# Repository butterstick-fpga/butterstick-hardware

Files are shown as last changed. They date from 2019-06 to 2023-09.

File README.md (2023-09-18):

# ButterStick

    A compact Lattice ECP5 based development board with breakouts for lots of high-speed I/O and serdes.

    With onboard DDR3, High Speed USB and Ethernet.

## Latest Revision: 
* __Latest Release:__ [ButterStick r1.0](hardware/ButterStick_r1.0/) 
  * Assembled PCBs available: [GroupGets](https://store.groupgets.com/products/butterstick-fpga-development-board)
  * Bare PCBs available: [Tindie](https://www.tindie.com/products/greeeg/butterstick-r10-bare-circuit-board)

Previous Revisions:
* [ButterStick r0.2](hardware/ButterStick_r0.2/)
* [ButterStick r0.1](hardware/ButterStick_r0.1/)

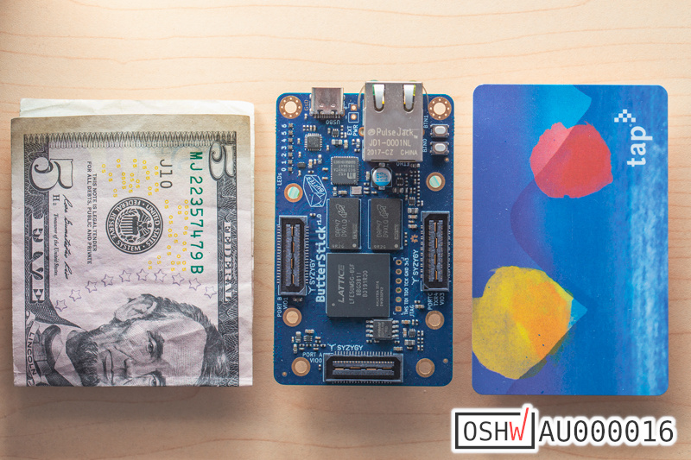
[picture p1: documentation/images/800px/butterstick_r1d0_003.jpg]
Populated ButterStick r1.0 board with Size Comparison


## Hardware (r1.0)

* ECP5 25F/45F/85F (BGA381 package)
* USB 2.0 High Speed (480 Mbit/s)
* Gigabit Ethernet
* upto 8Gbit DDR3L RAM (dual rank)
* 128Mbit QSPI FLASH Memory (Bitstream + User storage)
* MicroSD socket (4 bit SD interface)
* Onboard oscillators:
  * 30 MHz (ECP5's PLLs can create 60MHz,125MHz,etc.)
  * 25 MHz (RGMII PHY)
* 0.1" pitch JTAG connector
* 7x User RGB LEDs
* 2x User Buttons
* 2x Standard [SYZYGY compatible connectors](https://syzygyfpga.io/)
  * Adjustable VCCIO 1.2V-3.3V
  * Up to 32 single ended I/O
  * 10 differential pairs
  * Dedicated clock input pins
* 1x Transceiver [SYZYGY compatible connector](https://syzygyfpga.io/)
  * Adjustable VCCIO 1.2V-3.3V
  * Up to 14 single ended I/O
  * 2x/4x Lanes TX (5 Gbps SERDES)
  * 2x/4x Lanes RX (5 Gbps SERDES)
  * 1x Reference clock input

Board dimensions: 80mm x 49mm

### Variants

The ButterStick can be configured in different variants,
the part number defines which FPGA and DDR3 parts are installed.

`ButterStick-r1.0-[Memory gigabits]-[FPGA density]`

| | ButterStick-r1.0-2G-25F | ButterStick-r1.0-2G-85F | ButterStick-r1.0-8G-85F | 
|---|---|---|---|
| FPGA  | LFE5UM5G-25F-8BG381C | LFE5UM5G-85F-8BG381C | LFE5UM5G-85F-8BG381C | 
| DDR3  | 2x MT41K64M16TW-107 | 2x MT41K64M16TW-107 | 2x MT41K256M16TW-107 |

The 25F also has the following limitations on the ButterStick:
* 25F Only provides 2x SERDES lanes.
* 25F does not connect I/O pins S8/S9 on SYZYGY.C

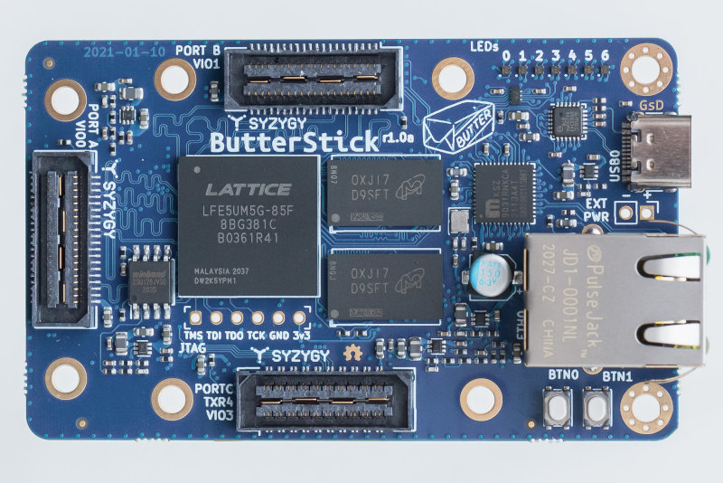
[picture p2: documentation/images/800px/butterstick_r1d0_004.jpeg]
Populated r1.0 board front

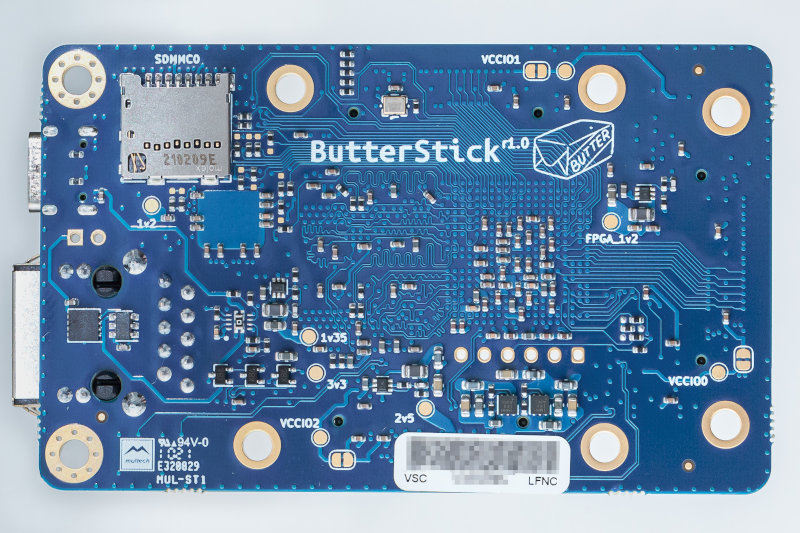
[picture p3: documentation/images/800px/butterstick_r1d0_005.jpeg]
Populated r1.0 board back


## Licence

 * Hardware in this repository is licensed under CERN OHL v1.2

 ## Open Source Hardware
This board is an OSHWA approved design: [AU000016](https://certification.oshwa.org/au000016.html)

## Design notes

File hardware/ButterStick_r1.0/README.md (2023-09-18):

# ButterStick r1.0
## ECP5 SYZYGY development board.
 
---

## What is it?
ECP5 based development board with on-board Gigabit Ethernet, High speed USB, and Lots of I/O broken out on SYZYGY connectors.

## Hardware Overview 
* Lattice ECP5-45F/85F FPGA in BGA381 package
* DDR3L Memory (dual rank)
* USB-C USB2.0 connection
    * High-speed (480Mbit) ULPI PHY
* Non-volatile Storage
    * 128Mbit QSPI FLASH Memory 
    * MicroSD socket
        * 4bit SD interface (CK, CMD, DAT0-3)
* Power supply
    * USB-C 5V input.
    * Aux 5V power input.
* onboard oscillator
    * 60Mhz
    * 25MHz (RGMII PHY)
* 0.1" JTAG connector
* User I/O
    * 2x Button 
    * 7x RGB LED
* Board dimensions
    * Dimensions: 80mm x 49mm (Golden Ratio!)

---

## Licence

 * Hardware in this repository is licensed under CERN OHL v1.2

## Open Source Hardware
This board is an OSHWA approved design: [AU000016](https://certification.oshwa.org/au000016.html)

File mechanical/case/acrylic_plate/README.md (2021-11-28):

# Acrylic Plate for Butterstick

This is a basic acrylic plate for butterstick described in openscad.  A dxf file is included for laser cutting.

It was cut in 3mm acrylic. The hardware is all M3, the bolts are 12mm long, the spacers are 5mm high.

Files are free to use in any form, no warranty is offered or implied.

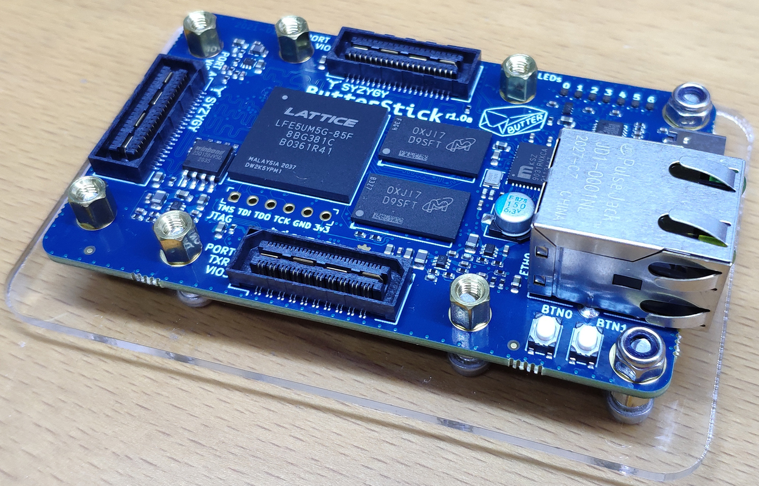
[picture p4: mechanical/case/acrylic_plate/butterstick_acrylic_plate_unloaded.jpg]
Loaded


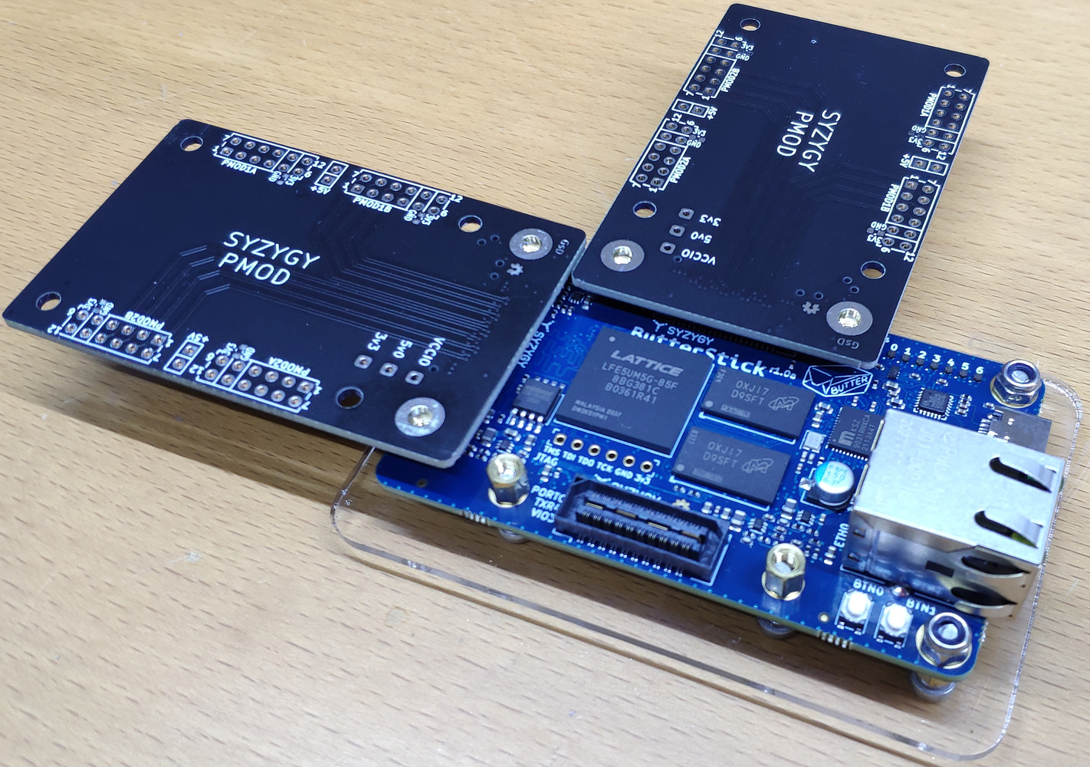
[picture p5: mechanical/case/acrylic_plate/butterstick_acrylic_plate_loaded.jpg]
Unloaded


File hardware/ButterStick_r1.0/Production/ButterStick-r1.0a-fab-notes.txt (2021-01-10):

Part number:        ButterStick-r1.0a

General fabrication notes

    * Boards panelised in 2x1 pattern using tab/route.
    * Board material is S1000-2
    
    * Blue solder mask on both sides of board.
    * High DPI White LPI legend on both sides of board.
    * Pad finish is ENIG.
    
    * All 0.2mm vias capped/filled/plated over (Via in Pad).

    * Finished board thickness is 1.6 mm.
    
    * Place UL mark/date code/manufacture logo on legend on backside of board.

Impedances

    Control to within 10%.
    Layer 1 microstrip (ref to layer 2)
        89 μm trace / 161 μm space = 100 ohm differential

    Layer 3 microstrip (ref to layer 2/4)
        89 μm trace / 161 μm space = 100 ohm differential
    
    Layer 6 microstrip (ref to layer 7/5)
        89 μm trace / 161 μm space = 100 ohm differential

    Layer 8 microstrip (ref to layer 7)
        89 μm trace / 161 μm space = 100 ohm differential

Suggested stackup
    1   35 μm (1 oz) copper         Signal
        0.075mm prepreg
    2   35 μm (1 oz) copper         Ground
        0.130mm core
    3   35 μm (1oz) copper          Signal
        prepreg as needed for 1.6mm finished PCB thickness
    4   35 μm (1 oz) copper         Power
        core as needed for 1.6mm finished PCB 
    5   35 μm (1oz) copper          Ground
        prepreg as needed for 1.6mm finished PCB thickness
    6   35 μm (1 oz) copper         Signal
        0.130mm core/prepreg
    7   35 μm (1 oz) copper         Ground
        0.075mm prepreg
    8   35 μm (1 oz) copper         Signal

File naming
    ButterStick.gko                  Board outline
    ButterStick-PTH.drl              Through-board plated holes
    ButterStick-NPTH.drl             Through-board unplated holes
    ButterStick.gto                  Front silkscreen
    ButterStick.gts                  Front solder mask
    ButterStick.gtl                  Layer 1 copper (Front)
    ButterStick.g2                   Layer 2 copper
    ButterStick.g3                   Layer 3 copper
    ButterStick.g4                   Layer 4 copper
    ButterStick.g5                   Layer 5 copper
    ButterStick.g6                   Layer 6 copper
    ButterStick.g7                   Layer 7 copper
    ButterStick.gbl                  Layer 8 copper (Back)
    ButterStick.gbs                  Back solder mask
    ButterStick.gbo                  Back silkscreen

    ButterStick.gtp                  Top Paste
    ButterStick.gbp                  Bottom Paste

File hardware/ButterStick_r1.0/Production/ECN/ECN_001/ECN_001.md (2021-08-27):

> Company: GsD / GroupGets  
> Project: ButterStick r1.0 

# Engineering Change Notice (ECN)

|||
|-|-|
**ECN Number** | 001  
**Origination Date** | Friday, 27th August, 2021
**Originator of Change** | Gregory Davill
**Project Name** | ButterStick r1.0
**Type of Action** | Part Substitution
**Reason for Change** | Remove difficult to source component from design

## Detailed description of changes

### Replace BOM item `U18`  
   ||Mfg|Part|
   |-|-|-|
   **Old** | Texas Instruments| TPS2121RUXR  
   **New** | YAGEO| RC0603JR-130RL  

### Populate new part on PCB
   Install `U18` such that it shorts pins 1,2 and 7,8 of `U18`  
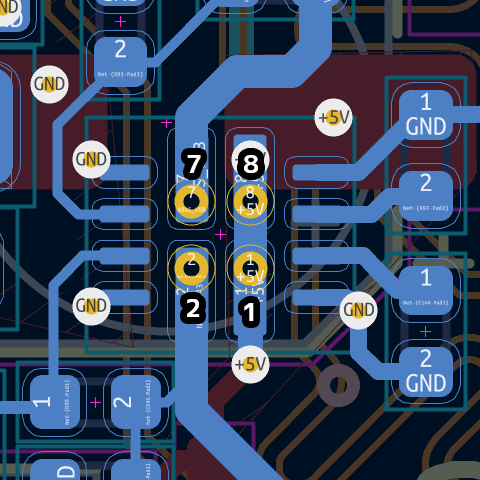
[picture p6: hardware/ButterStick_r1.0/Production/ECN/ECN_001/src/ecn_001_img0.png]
ecn_001_img0
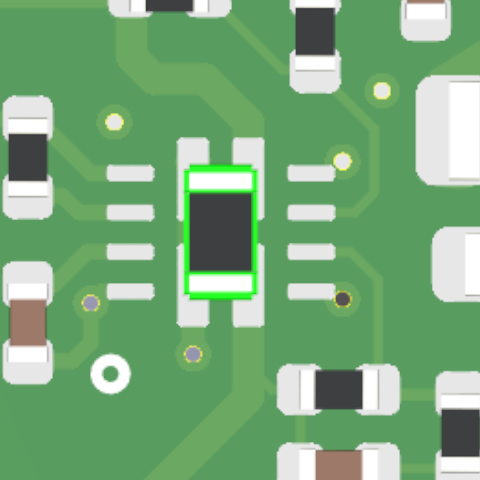
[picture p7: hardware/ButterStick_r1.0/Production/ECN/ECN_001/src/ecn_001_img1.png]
ecn_001_img1
      

> Note CAD view is Top view (Through the PCB). Whereas render view is Bottom View.

## QC checks

 Skew of `U18` is acceptable, and expected.  
 Acceptance criteria on soldering is that it's successfully soldered across pins 1,2 and 7,8 of `U18`

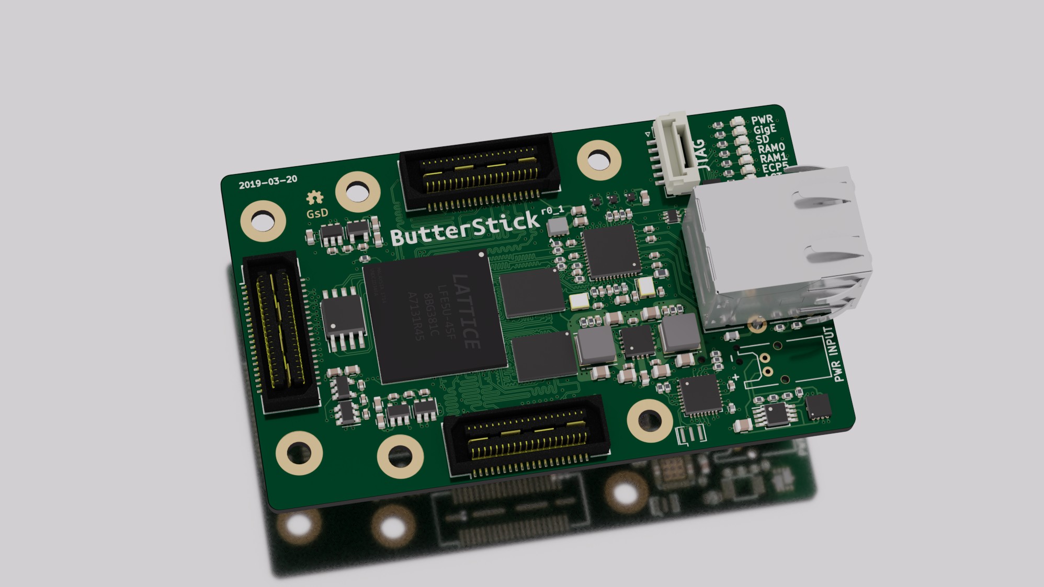
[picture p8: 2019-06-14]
hardware/ButterStick_r0.1/plot/render_001.jpg

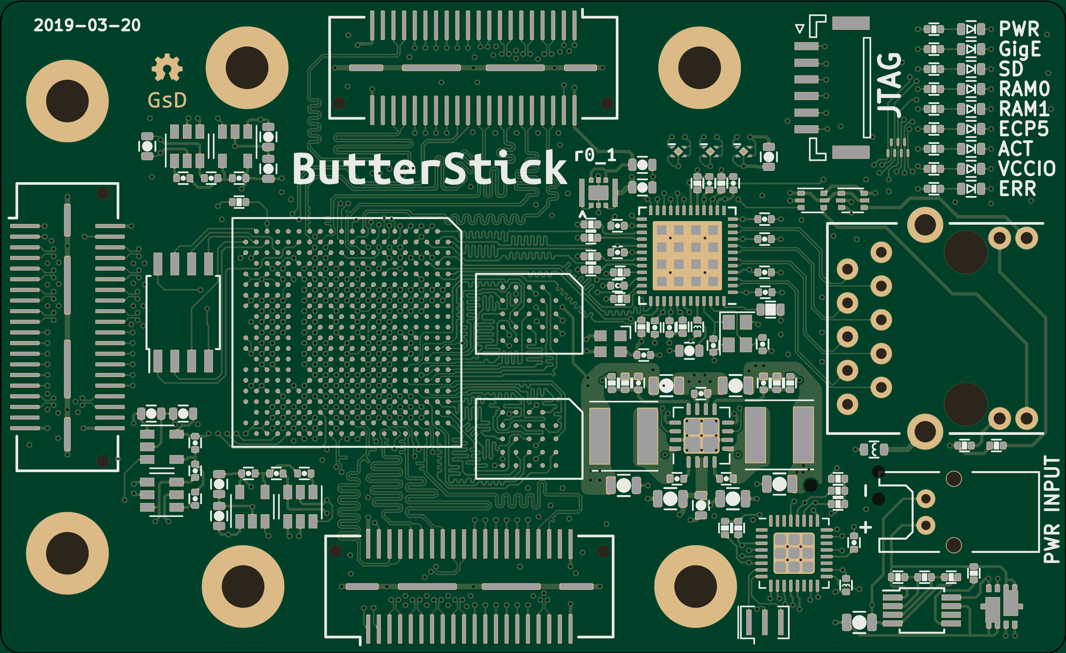
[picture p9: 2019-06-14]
hardware/ButterStick_r0.1/plot/ButterStick-Front.png

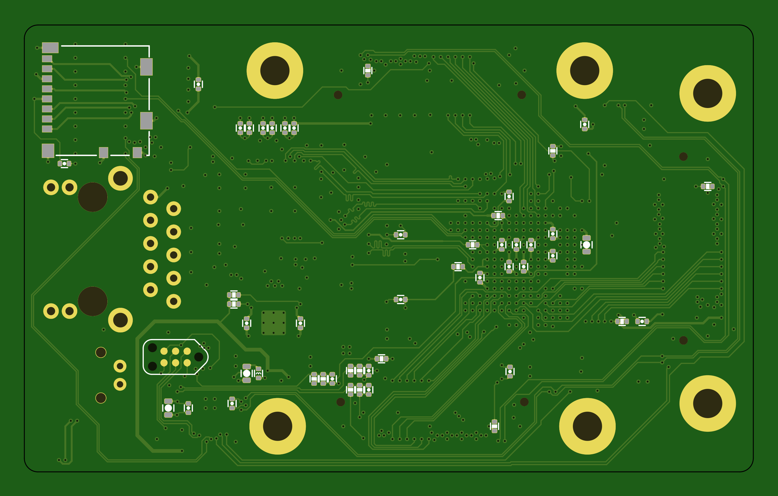
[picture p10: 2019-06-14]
hardware/ButterStick_r0.1/plot/ButterStick-Back.png

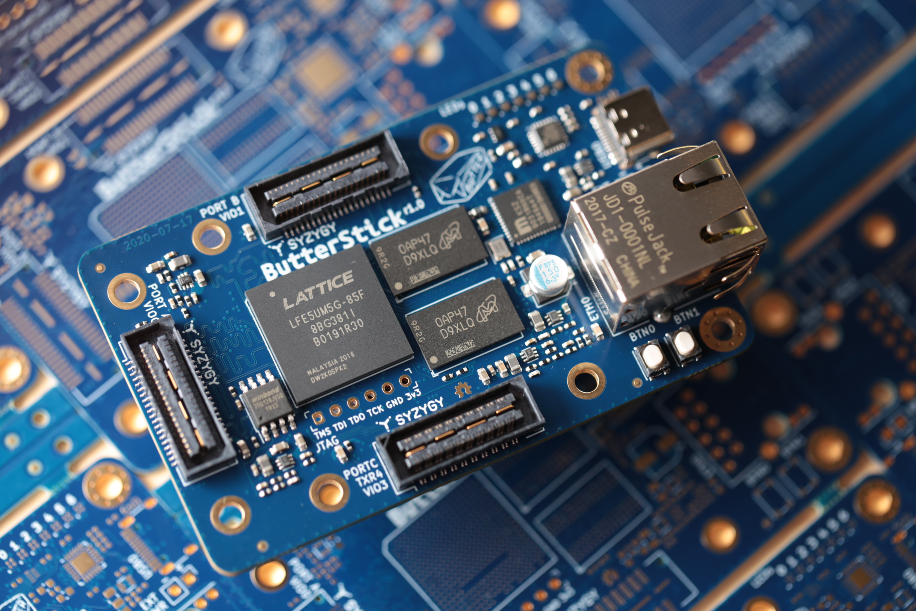
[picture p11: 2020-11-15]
documentation/images/butterstick_r1d0_001.jpeg

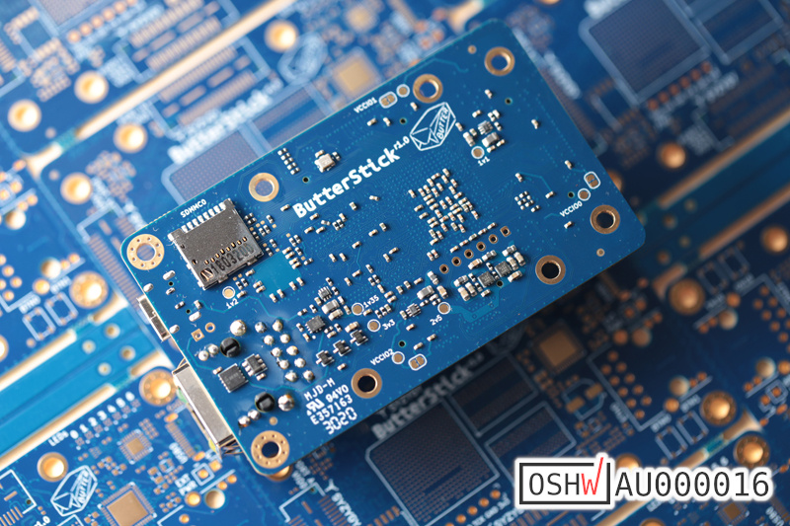
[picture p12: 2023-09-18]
documentation/images/800px/butterstick_r1d0_002.jpg

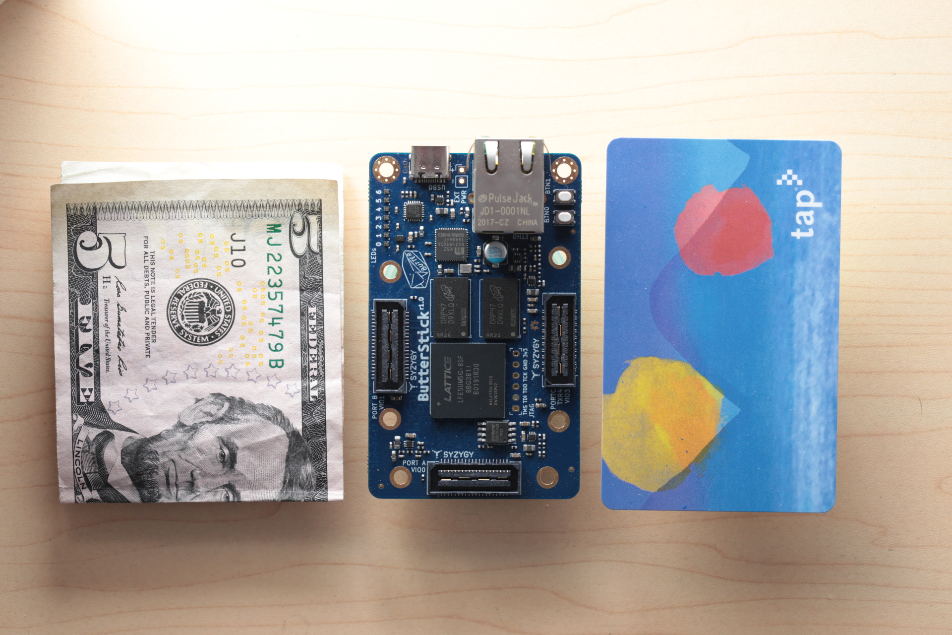
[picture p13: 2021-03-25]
documentation/images/butterstick_r1d0_003.jpeg

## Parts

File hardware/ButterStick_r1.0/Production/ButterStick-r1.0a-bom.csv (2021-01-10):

Source: | /home/greg/Projects/ButterStick/hardware/ButterStick_r1.0/ButterStick.kicad_sch
Date: | Sun 10 Jan 2021 21:55:18
Tool: | Eeschema 5.99.0-unknown-af2219ba7f~106~ubuntu20.10.1
Generator: | /usr/share/kicad/plugins/bom_csv_grouped_by_value.py
Component Count: | 325
Individual Components:
Item | Qty | Reference(s) | Value | LibPart | Footprint | Datasheet | Mfg | PN | Tol | manf#
 |  | C1 | 0.1uF | Device:C | Capacitor_SMD:C_0402_1005Metric | ~ | Yageo | CC0402KRX5R6BB104 | 10V / X5R
 |  | C2 | 1uF | Device:C | Capacitor_SMD:C_0402_1005Metric | ~ | Yageo | CC0402KRX5R6BB105
 |  | C3 | 1uF | Device:C | Capacitor_SMD:C_0402_1005Metric | ~ | Yageo | CC0402KRX5R6BB105
 |  | C4 | 0.1uF | Device:C | Capacitor_SMD:C_0402_1005Metric | ~ | Yageo | CC0402KRX5R6BB104 | 10V / X5R
 |  | C5 | 0.1uF | Device:C | Capacitor_SMD:C_0402_1005Metric | ~ | Yageo | CC0402KRX5R6BB104 | 10V / X5R
 |  | C6 | 0.01uF | Device:C | Capacitor_SMD:C_0402_1005Metric | ~ | Yageo | CC0402KRX7R8BB103
 |  | C7 | 0.1uF | Device:C | Capacitor_SMD:C_0402_1005Metric | ~ | Yageo | CC0402KRX5R6BB104 | 10V / X5R
 |  | C8 | 0.1uF | Device:C | Capacitor_SMD:C_0402_1005Metric | ~ | Yageo | CC0402KRX5R6BB104 | 10V / X5R
 |  | C9 | 0.1uF | Device:C | Capacitor_SMD:C_0402_1005Metric | ~ | Yageo | CC0402KRX5R6BB104 | 10V / X5R
 |  | C10 | 10uF | Device:C | Capacitor_SMD:C_0603_1608Metric | ~ | Yageo | CC0603KRX5R5BB106
 |  | C11 | 0.1uF | Device:C | Capacitor_SMD:C_0402_1005Metric | ~ | Yageo | CC0402KRX5R6BB104 | 10V / X5R
 |  | C12 | 0.1uF | Device:C | Capacitor_SMD:C_0402_1005Metric | ~ | Yageo | CC0402KRX5R6BB104 | 10V / X5R
 |  | C13 | 0.1uF | Device:C | Capacitor_SMD:C_0402_1005Metric | ~ | Yageo | CC0402KRX5R6BB104 | 10V / X5R
 |  | C14 | 0.1uF | Device:C | Capacitor_SMD:C_0402_1005Metric | ~ | Yageo | CC0402KRX5R6BB104 | 10V / X5R
 |  | C15 | 0.1uF | Device:C | Capacitor_SMD:C_0402_1005Metric | ~ | Yageo | CC0402KRX5R6BB104 | 10V / X5R
 |  | C16 | 0.1uF | Device:C | Capacitor_SMD:C_0402_1005Metric | ~ | Yageo | CC0402KRX5R6BB104 | 10V / X5R
 |  | C17 | 0.1uF | Device:C | Capacitor_SMD:C_0402_1005Metric | ~ | Yageo | CC0402KRX5R6BB104 | 10V / X5R
 |  | C18 | 6.8pF | Device:C | Capacitor_SMD:C_0402_1005Metric | ~ | Yageo | CC0402CRNPO9BN6R8
 |  | C19 | 6.8pF | Device:C | Capacitor_SMD:C_0402_1005Metric | ~ | Yageo | CC0402CRNPO9BN6R8
 |  | C20 | 0.1uF | Device:C | Capacitor_SMD:C_0402_1005Metric | ~ | Yageo | CC0402KRX5R6BB104 | 10V / X5R
 |  | C21 | 0.1uF | Device:C | Capacitor_SMD:C_0402_1005Metric | ~ | Yageo | CC0402KRX5R6BB104 | 10V / X5R
 |  | C22 | 0.1uF | Device:C | Capacitor_SMD:C_0402_1005Metric | ~ | Yageo | CC0402KRX5R6BB104 | 10V / X5R
 |  | C23 | 0.47uF | Device:C | Capacitor_SMD:C_0402_1005Metric |  | Yageo | CC0402KRX5R5BB474
 |  | C24 | 0.1uF | Device:C | Capacitor_SMD:C_0402_1005Metric |  | Yageo | CC0402KRX5R6BB104 | 10V / X5R
 |  | C25 | 0.47uF | Device:C | Capacitor_SMD:C_0402_1005Metric |  | Yageo | CC0402KRX5R5BB474
 |  | C26 | 0.1uF | Device:C | Capacitor_SMD:C_0402_1005Metric |  | Yageo | CC0402KRX5R6BB104 | 10V / X5R
 |  | C27 | 0.47uF | Device:C | Capacitor_SMD:C_0402_1005Metric |  | Yageo | CC0402KRX5R5BB474
 |  | C28 | 0.1uF | Device:C | Capacitor_SMD:C_0402_1005Metric |  | Yageo | CC0402KRX5R6BB104 | 10V / X5R
 |  | C29 | 4.7uF | Device:C | Capacitor_SMD:C_0402_1005Metric | ~ | Yageo | CC0402KRX5R6BB475
 |  | C30 | 0.47uF | Device:C | Capacitor_SMD:C_0402_1005Metric |  | Yageo | CC0402KRX5R5BB474
 |  | C31 | 4.7uF | Device:C | Capacitor_SMD:C_0402_1005Metric |  | Yageo | CC0402KRX5R6BB475
 |  | C32 | 0.1uF | Device:C | Capacitor_SMD:C_0402_1005Metric |  | Yageo | CC0402KRX5R6BB104 | 10V / X5R
 |  | C33 | 1uF | Device:C | Capacitor_SMD:C_0402_1005Metric | ~ | Yageo | CC0402KRX5R6BB105
 |  | C34 | 1uF | Device:C | Capacitor_SMD:C_0402_1005Metric | ~ | Yageo | CC0402KRX5R6BB105
 |  | C35 | 1uF | Device:C | Capacitor_SMD:C_0402_1005Metric | ~ | Yageo | CC0402KRX5R6BB105
 |  | C36 | 1uF | Device:C | Capacitor_SMD:C_0402_1005Metric | ~ | Yageo | CC0402KRX5R6BB105
 |  | C37 | 1uF | Device:C | Capacitor_SMD:C_0402_1005Metric | ~ | Yageo | CC0402KRX5R6BB105
 |  | C38 | 0.1uF | Device:C | Capacitor_SMD:C_0402_1005Metric |  | Yageo | CC0402KRX5R6BB104 | 10V / X5R
 |  | C39 | 0.1uF | Device:C | Capacitor_SMD:C_0402_1005Metric |  | Yageo | CC0402KRX5R6BB104 | 10V / X5R
 |  | C40 | 0.1uF | Device:C | Capacitor_SMD:C_0402_1005Metric |  | Yageo | CC0402KRX5R6BB104 | 10V / X5R
 |  | C41 | 10uF | Device:C | Capacitor_SMD:C_0603_1608Metric |  | Yageo | CC0603KRX5R5BB106
 |  | C42 | 0.1uF | Device:C | Capacitor_SMD:C_0402_1005Metric |  | Yageo | CC0402KRX5R6BB104 | 10V / X5R
 |  | C43 | 0.47uF | Device:C | Capacitor_SMD:C_0402_1005Metric |  | Yageo | CC0402KRX5R5BB474
 |  | C44 | 0.1uF | Device:C | Capacitor_SMD:C_0402_1005Metric |  | Yageo | CC0402KRX5R6BB104 | 10V / X5R
 |  | C45 | 0.47uF | Device:C | Capacitor_SMD:C_0402_1005Metric |  | Yageo | CC0402KRX5R5BB474
 |  | C46 | 0.1uF | Device:C | Capacitor_SMD:C_0402_1005Metric |  | Yageo | CC0402KRX5R6BB104 | 10V / X5R
 |  | C47 | 0.47uF | Device:C | Capacitor_SMD:C_0402_1005Metric |  | Yageo | CC0402KRX5R5BB474
 |  | C48 | 0.1uF | Device:C | Capacitor_SMD:C_0402_1005Metric |  | Yageo | CC0402KRX5R6BB104 | 10V / X5R
 |  | C49 | 0.47uF | Device:C | Capacitor_SMD:C_0402_1005Metric |  | Yageo | CC0402KRX5R5BB474
 |  | C50 | 0.1uF | Device:C | Capacitor_SMD:C_0402_1005Metric |  | Yageo | CC0402KRX5R6BB104 | 10V / X5R
 |  | C51 | 0.47uF | Device:C | Capacitor_SMD:C_0402_1005Metric |  | Yageo | CC0402KRX5R5BB474
 |  | C52 | 0.1uF | Device:C | Capacitor_SMD:C_0402_1005Metric |  | Yageo | CC0402KRX5R6BB104 | 10V / X5R
 |  | C53 | 0.1uF | Device:C | Capacitor_SMD:C_0402_1005Metric |  | Yageo | CC0402KRX5R6BB104 | 10V / X5R
 |  | C54 | 6.8pF | Device:C | Capacitor_SMD:C_0402_1005Metric | ~ | Yageo | CC0402CRNPO9BN6R8
 |  | C55 | 10uF | Device:C | Capacitor_SMD:C_0603_1608Metric | ~ | Yageo | CC0603KRX5R5BB106
 |  | C56 | 0.1uF | Device:C | Capacitor_SMD:C_0402_1005Metric |  | Yageo | CC0402KRX5R6BB104 | 10V / X5R
 |  | C57 | 10uF | Device:C | Capacitor_SMD:C_0603_1608Metric |  | Yageo | CC0603KRX5R5BB106
 |  | C58 | 22uF | Device:C | Capacitor_SMD:C_0603_1608Metric | ~ | Yageo | CC0603MRX5R5BB226 | 6.3V
 |  | C59 | 22uF | Device:C | Capacitor_SMD:C_0603_1608Metric | ~ | Yageo | CC0603MRX5R5BB226 | 6.3V
 |  | C60 | 4.7uF | Device:C | Capacitor_SMD:C_0402_1005Metric | ~ | Yageo | CC0402KRX5R6BB475
 |  | C61 | 4.7uF | Device:C | Capacitor_SMD:C_0402_1005Metric | ~ | Yageo | CC0402KRX5R6BB475
 |  | C62 | 4.7uF | Device:C | Capacitor_SMD:C_0402_1005Metric | ~ | Yageo | CC0402KRX5R6BB475
 |  | C63 | 0.1uF | Device:C | Capacitor_SMD:C_0402_1005Metric |  | Yageo | CC0402KRX5R6BB104 | 10V / X5R
 |  | C64 | 0.1uF | Device:C | Capacitor_SMD:C_0402_1005Metric |  | Yageo | CC0402KRX5R6BB104 | 10V / X5R
 |  | C65 | 10uF | Device:C | Capacitor_SMD:C_0603_1608Metric |  | Yageo | CC0603KRX5R5BB106
 |  | C66 | 0.1uF | Device:C | Capacitor_SMD:C_0402_1005Metric |  | Yageo | CC0402KRX5R6BB104 | 10V / X5R
 |  | C67 | 0.1uF | Device:C | Capacitor_SMD:C_0402_1005Metric |  | Yageo | CC0402KRX5R6BB104 | 10V / X5R
 |  | C68 | 1uF | Device:C | Capacitor_SMD:C_0402_1005Metric |  | Yageo | CC0402KRX5R6BB105
 |  | C69 | 10uF | Device:C | Capacitor_SMD:C_0603_1608Metric |  | Yageo | CC0603KRX5R5BB106
 |  | C70 | 0.1uF | Device:C | Capacitor_SMD:C_0402_1005Metric |  | Yageo | CC0402KRX5R6BB104 | 10V / X5R
 |  | C71 | 0.1uF | Device:C | Capacitor_SMD:C_0402_1005Metric |  | Yageo | CC0402KRX5R6BB104 | 10V / X5R
 |  | C72 | 10uF | Device:C | Capacitor_SMD:C_0603_1608Metric |  | Yageo | CC0603KRX5R5BB106
 |  | C73 | 6.8pF | Device:C | Capacitor_SMD:C_0402_1005Metric | ~ | Yageo | CC0402CRNPO9BN6R8
 |  | C74 | 10uF | Device:C | Capacitor_SMD:C_0603_1608Metric | ~ | Yageo | CC0603KRX5R5BB106
 |  | C75 | 1uF | Device:C | Capacitor_SMD:C_0402_1005Metric | ~ | Yageo | CC0402KRX5R6BB105
 |  | C76 | 4.7uF | Device:C | Capacitor_SMD:C_0402_1005Metric | ~ | Yageo | CC0402KRX5R6BB475
 |  | C77 | 4.7uF | Device:C | Capacitor_SMD:C_0402_1005Metric | ~ | Yageo | CC0402KRX5R6BB475
 |  | C78 | 4.7uF | Device:C | Capacitor_SMD:C_0402_1005Metric | ~ | Yageo | CC0402KRX5R6BB475
 |  | C79 | 6.8pF | Device:C | Capacitor_SMD:C_0402_1005Metric | ~ | Yageo | CC0402CRNPO9BN6R8
 |  | C80 | 6.8pF | Device:C | Capacitor_SMD:C_0402_1005Metric | ~ | Yageo | CC0402CRNPO9BN6R8
 |  | C81 | 6.8pF | Device:C | Capacitor_SMD:C_0402_1005Metric | ~ | Yageo | CC0402CRNPO9BN6R8
 |  | C82 | 10uF | Device:C | Capacitor_SMD:C_0603_1608Metric | ~ | Yageo | CC0603KRX5R5BB106
 |  | C83 | 10uF | Device:C | Capacitor_SMD:C_0603_1608Metric | ~ | Yageo | CC0603KRX5R5BB106
 |  | C84 | 10uF | Device:C | Capacitor_SMD:C_0603_1608Metric | ~ | Yageo | CC0603KRX5R5BB106
 |  | C85 | 1uF | Device:C | Capacitor_SMD:C_0402_1005Metric | ~ | Yageo | CC0402KRX5R6BB105
 |  | C86 | 1uF | Device:C | Capacitor_SMD:C_0402_1005Metric | ~ | Yageo | CC0402KRX5R6BB105
 |  | C87 | 1uF | Device:C | Capacitor_SMD:C_0402_1005Metric | ~ | Yageo | CC0402KRX5R6BB105
 |  | C88 | 0.1uF | Device:C | Capacitor_SMD:C_0402_1005Metric | ~ | Yageo | CC0402KRX5R6BB104 | 10V / X5R
 |  | C89 | 0.1uF | Device:C | Capacitor_SMD:C_0402_1005Metric | ~ | Yageo | CC0402KRX5R6BB104 | 10V / X5R
 |  | C90 | 4.7uF | Device:C | Capacitor_SMD:C_0402_1005Metric | ~ | Yageo | CC0402KRX5R6BB475
 |  | C91 | 4.7uF | Device:C | Capacitor_SMD:C_0402_1005Metric | ~ | Yageo | CC0402KRX5R6BB475
 |  | C92 | 0.1uF | Device:C | Capacitor_SMD:C_0402_1005Metric | ~ | Yageo | CC0402KRX5R6BB104 | 10V / X5R
 |  | C93 | 0.1uF | Device:C | Capacitor_SMD:C_0402_1005Metric | ~ | Yageo | CC0402KRX5R6BB104 | 10V / X5R
 |  | C94 | 0.1uF | Device:C | Capacitor_SMD:C_0402_1005Metric | ~ | Yageo | CC0402KRX5R6BB104 | 10V / X5R
 |  | C95 | 4.7uF | Device:C | Capacitor_SMD:C_0402_1005Metric | ~ | Yageo | CC0402KRX5R6BB475
 |  | C96 | 4.7uF | Device:C | Capacitor_SMD:C_0402_1005Metric | ~ | Yageo | CC0402KRX5R6BB475
 |  | C97 | 0.1uF | Device:C | Capacitor_SMD:C_0402_1005Metric | ~ | Yageo | CC0402KRX5R6BB104 | 10V / X5R
 |  | C98 | 0.1uF | Device:C | Capacitor_SMD:C_0402_1005Metric | ~ | Yageo | CC0402KRX5R6BB104 | 10V / X5R
 |  | C99 | 0.1uF | Device:C | Capacitor_SMD:C_0402_1005Metric | ~ | Yageo | CC0402KRX5R6BB104 | 10V / X5R
 |  | C100 | 6.8pF | Device:C | Capacitor_SMD:C_0402_1005Metric | ~ | Yageo | CC0402CRNPO9BN6R8
 |  | C101 | 10uF | Device:C | Capacitor_SMD:C_0603_1608Metric | ~ | Yageo | CC0603KRX5R5BB106
 |  | C102 | 0.1uF | Device:C | Capacitor_SMD:C_0402_1005Metric | ~ | Yageo | CC0402KRX5R6BB104 | 10V / X5R
 |  | C103 | 10uF | Device:C | Capacitor_SMD:C_0603_1608Metric | ~ | Yageo | CC0603KRX5R5BB106
 |  | C104 | 10uF | Device:C | Capacitor_SMD:C_0603_1608Metric | ~ | Yageo | CC0603KRX5R5BB106
 |  | C105 | 0.1uF | Device:C | Capacitor_SMD:C_0402_1005Metric | ~ | Yageo | CC0402KRX5R6BB104 | 10V / X5R
 |  | C106 | 0.1uF | Device:C | Capacitor_SMD:C_0402_1005Metric | ~ | Yageo | CC0402KRX5R6BB104 | 10V / X5R
 |  | C107 | 6.8pF | Device:C | Capacitor_SMD:C_0402_1005Metric | ~ | Yageo | CC0402CRNPO9BN6R8
 |  | C108 | 10uF | Device:C | Capacitor_SMD:C_0603_1608Metric | ~ | Yageo | CC0603KRX5R5BB106
 |  | C109 | 0.1uF | Device:C | Capacitor_SMD:C_0402_1005Metric | ~ | Yageo | CC0402KRX5R6BB104 | 10V / X5R
 |  | C110 | 10uF | Device:C | Capacitor_SMD:C_0603_1608Metric | ~ | Yageo | CC0603KRX5R5BB106
 |  | C111 | 10uF | Device:C | Capacitor_SMD:C_0603_1608Metric | ~ | Yageo | CC0603KRX5R5BB106
 |  | C112 | 0.1uF | Device:C | Capacitor_SMD:C_0402_1005Metric | ~ | Yageo | CC0402KRX5R6BB104 | 10V / X5R
 |  | C113 | 0.1uF | Device:C | Capacitor_SMD:C_0402_1005Metric | ~ | Yageo | CC0402KRX5R6BB104 | 10V / X5R
 |  | C114 | 6.8pF | Device:C | Capacitor_SMD:C_0402_1005Metric | ~ | Yageo | CC0402CRNPO9BN6R8
 |  | C115 | 10uF | Device:C | Capacitor_SMD:C_0603_1608Metric | ~ | Yageo | CC0603KRX5R5BB106
 |  | C116 | 0.1uF | Device:C | Capacitor_SMD:C_0402_1005Metric | ~ | Yageo | CC0402KRX5R6BB104 | 10V / X5R
 |  | C117 | 10uF | Device:C | Capacitor_SMD:C_0603_1608Metric | ~ | Yageo | CC0603KRX5R5BB106
 |  | C118 | 10uF | Device:C | Capacitor_SMD:C_0603_1608Metric | ~ | Yageo | CC0603KRX5R5BB106
 |  | C119 | 4.7uF | Device:C | Capacitor_SMD:C_0402_1005Metric | ~ | Yageo | CC0402KRX5R6BB475
 |  | C120 | 0.1uF | Device:C | Capacitor_SMD:C_0402_1005Metric | ~ | Yageo | CC0402KRX5R6BB104 | 10V / X5R
 |  | C121 | 0.1uF | Device:C | Capacitor_SMD:C_0402_1005Metric | ~ | Yageo | CC0402KRX5R6BB104 | 10V / X5R
 |  | C122 | 0.47uF | Device:C | Capacitor_SMD:C_0402_1005Metric | ~ | Yageo | CC0402KRX5R5BB474
 |  | C123 | 0.47uF | Device:C | Capacitor_SMD:C_0402_1005Metric | ~ | Yageo | CC0402KRX5R5BB474
 |  | C124 | 0.47uF | Device:C | Capacitor_SMD:C_0402_1005Metric | ~ | Yageo | CC0402KRX5R5BB474
 |  | C125 | 0.47uF | Device:C | Capacitor_SMD:C_0402_1005Metric | ~ | Yageo | CC0402KRX5R5BB474
 |  | C126 | 0.47uF | Device:C | Capacitor_SMD:C_0402_1005Metric | ~ | Yageo | CC0402KRX5R5BB474
 |  | C127 | 0.47uF | Device:C | Capacitor_SMD:C_0402_1005Metric | ~ | Yageo | CC0402KRX5R5BB474
 |  | C128 | 0.01uF | Device:C | Capacitor_SMD:C_0402_1005Metric | ~ | Yageo | CC0402KRX7R8BB103
 |  | C129 | 0.01uF | Device:C | Capacitor_SMD:C_0402_1005Metric | ~ | Yageo | CC0402KRX7R8BB103
 |  | C130 | 0.01uF | Device:C | Capacitor_SMD:C_0402_1005Metric | ~ | Yageo | CC0402KRX7R8BB103
 |  | C131 | 0.01uF | Device:C | Capacitor_SMD:C_0402_1005Metric | ~ | Yageo | CC0402KRX7R8BB103
 |  | C132 | 0.47uF | Device:C | Capacitor_SMD:C_0402_1005Metric | ~ | Yageo | CC0402KRX5R5BB474
 |  | C133 | 0.47uF | Device:C | Capacitor_SMD:C_0402_1005Metric | ~ | Yageo | CC0402KRX5R5BB474
 |  | C134 | 0.47uF | Device:C | Capacitor_SMD:C_0402_1005Metric | ~ | Yageo | CC0402KRX5R5BB474
 |  | C135 | 0.47uF | Device:C | Capacitor_SMD:C_0402_1005Metric | ~ | Yageo | CC0402KRX5R5BB474
 |  | C136 | 0.47uF | Device:C | Capacitor_SMD:C_0402_1005Metric | ~ | Yageo | CC0402KRX5R5BB474
 |  | C137 | 0.47uF | Device:C | Capacitor_SMD:C_0402_1005Metric | ~ | Yageo | CC0402KRX5R5BB474
 |  | C138 | 4.7uF | Device:C | Capacitor_SMD:C_0402_1005Metric | ~ | Yageo | CC0402KRX5R6BB475
 |  | C139 | 4.7uF | Device:C | Capacitor_SMD:C_0402_1005Metric | ~ | Yageo | CC0402KRX5R6BB475
 |  | C140 | 22uF | Device:C | Capacitor_SMD:C_0603_1608Metric | ~ | Yageo | CC0603MRX5R5BB226 | 6.3V
 |  | C141 | 22uF | Device:C | Capacitor_SMD:C_0603_1608Metric | ~ | Yageo | CC0603MRX5R5BB226 | 6.3V
 |  | C142 | 1uF | Device:C | Capacitor_SMD:C_0402_1005Metric | ~ | Yageo | CC0402KRX5R6BB105
 |  | C143 | 1uF | Device:C | Capacitor_SMD:C_0402_1005Metric |  | Yageo | CC0402KRX5R6BB105
 |  | C144 | 0.01uF | Device:C | Capacitor_SMD:C_0402_1005Metric | ~ | Yageo | CC0402KRX7R8BB103
 |  | C145 | 0.1uF | Device:C | Capacitor_SMD:C_0402_1005Metric | ~ | Yageo | CC0402KRX5R6BB104 | 10V / X5R
 |  | C146 | 0.1uF | Device:C | Capacitor_SMD:C_0402_1005Metric | ~ | Yageo | CC0402KRX5R6BB104 | 10V / X5R
 |  | C147 | 0.1uF | Device:C | Capacitor_SMD:C_0402_1005Metric | ~ | Yageo | CC0402KRX5R6BB104 | 10V / X5R
 |  | C148 | 0.1uF | Device:C | Capacitor_SMD:C_0402_1005Metric | ~ | Yageo | CC0402KRX5R6BB104 | 10V / X5R
 |  | C149 | 0.1uF | Device:C | Capacitor_SMD:C_0402_1005Metric | ~ | Yageo | CC0402KRX5R6BB104 | 10V / X5R
 |  | C150 | 0.1uF | Device:C | Capacitor_SMD:C_0402_1005Metric | ~ | Yageo | CC0402KRX5R6BB104 | 10V / X5R
 |  | C151 | 0.1uF | Device:C | Capacitor_SMD:C_0402_1005Metric |  | Yageo | CC0402KRX5R6BB104 | 10V / X5R
 |  | C152 | 0.47uF | Device:C | Capacitor_SMD:C_0402_1005Metric |  | Yageo | CC0402KRX5R5BB474
 |  | C153 | 0.1uF | Device:C | Capacitor_SMD:C_0402_1005Metric |  | Yageo | CC0402KRX5R6BB104 | 10V / X5R
 |  | C154 | 0.1uF | Device:C | Capacitor_SMD:C_0402_1005Metric |  | Yageo | CC0402KRX5R6BB104 | 10V / X5R
 |  | C155 | 0.1uF | Device:C | Capacitor_SMD:C_0402_1005Metric |  | Yageo | CC0402KRX5R6BB104 | 10V / X5R
 |  | C156 | 0.1uF | Device:C | Capacitor_SMD:C_0402_1005Metric |  | Yageo | CC0402KRX5R6BB104 | 10V / X5R
 |  | C157 | 0.1uF | Device:C | Capacitor_SMD:C_0402_1005Metric |  | Yageo | CC0402KRX5R6BB104 | 10V / X5R
 |  | C158 | 0.1uF | Device:C | Capacitor_SMD:C_0402_1005Metric |  | Yageo | CC0402KRX5R6BB104 | 10V / X5R
 |  | C159 | 1uF | Device:C | Capacitor_SMD:C_0402_1005Metric | ~ | Yageo | CC0402KRX5R6BB105
 |  | C160 | 1uF | Device:C | Capacitor_SMD:C_0402_1005Metric | ~ | Yageo | CC0402KRX5R6BB105
 |  | C161 | 1uF | Device:C | Capacitor_SMD:C_0402_1005Metric | ~ | Yageo | CC0402KRX5R6BB105
 |  | C162 | 1uF | Device:C | Capacitor_SMD:C_0402_1005Metric | ~ | Yageo | CC0402KRX5R6BB105
 |  | C163 | 1uF | Device:C | Capacitor_SMD:C_0402_1005Metric | ~ | Yageo | CC0402KRX5R6BB105
 |  | C164 | 1uF | Device:C | Capacitor_SMD:C_0402_1005Metric | ~ | Yageo | CC0402KRX5R6BB105
 |  | C165 | 150uF | Device:CP1 | Capacitor_SMD:CP_Elec_5x4.4 | ~ | United Chemi-Con | APXF6R3ARA151ME40G
 |  | C166 | 1uF | Device:C | Capacitor_SMD:C_0402_1005Metric |  | Yageo | CC0402KRX5R6BB105
 |  | C167 | 0.1uF | Device:C | Capacitor_SMD:C_0402_1005Metric |  | Yageo | CC0402KRX5R6BB104 | 10V / X5R
 |  | CON1 | JD1_0001NL | gkl_misc:JD1_0001NL | gkl_conn:MAGJACK |  | Pulse Electronics Network | JD1-0001NL
 |  | D1 | RGB0404 | Device:LED_ARGB | gkl_led:0404LED_RGB | ~ | MEIHUA | MHPA1010RGBDT
 |  | D2 | RGB0404 | Device:LED_ARGB | gkl_led:0404LED_RGB | ~ | MEIHUA | MHPA1010RGBDT
 |  | D3 | RGB0404 | Device:LED_ARGB | gkl_led:0404LED_RGB | ~ | MEIHUA | MHPA1010RGBDT
 |  | D4 | RGB0404 | Device:LED_ARGB | gkl_led:0404LED_RGB | ~ | MEIHUA | MHPA1010RGBDT
 |  | D5 | RGB0404 | Device:LED_ARGB | gkl_led:0404LED_RGB | ~ | MEIHUA | MHPA1010RGBDT
 |  | D6 | RGB0404 | Device:LED_ARGB | gkl_led:0404LED_RGB | ~ | MEIHUA | MHPA1010RGBDT
 |  | D7 | RGB0404 | Device:LED_ARGB | gkl_led:0404LED_RGB | ~ | MEIHUA | MHPA1010RGBDT
 |  | FB1 | 100R | Device:Ferrite_Bead_Small | Inductor_SMD:L_0603_1608Metric | ~ | TDK Corporation | MPZ1608D101BTA00
 |  | FB2 | 100R | Device:Ferrite_Bead_Small | Inductor_SMD:L_0603_1608Metric | ~ | TDK Corporation | MPZ1608D101BTA00
 |  | FB3 | 100R | Device:Ferrite_Bead_Small | Inductor_SMD:L_0603_1608Metric | ~ | TDK Corporation | MPZ1608D101BTA00
 |  | FB4 | 100R | Device:Ferrite_Bead_Small | Inductor_SMD:L_0603_1608Metric | ~ | TDK Corporation | MPZ1608D101BTA00
 |  | FB5 | 100R | Device:Ferrite_Bead_Small | Inductor_SMD:L_0603_1608Metric | ~ | TDK Corporation | MPZ1608D101BTA00
 |  | FB6 | 100R | Device:Ferrite_Bead_Small | Inductor_SMD:L_0603_1608Metric | ~ | TDK Corporation | MPZ1608D101BTA00
 |  | FB7 | 100R | Device:Ferrite_Bead_Small | Inductor_SMD:L_0603_1608Metric | ~ | TDK Corporation | MPZ1608D101BTA00
 |  | FID1 | Fiducial | Mechanical:Fiducial | Fiducial:Fiducial_0.75mm_Mask1.5mm | ~ |  | DNP
 |  | FID2 | Fiducial | Mechanical:Fiducial | Fiducial:Fiducial_0.75mm_Mask1.5mm | ~ |  | DNP
 |  | FID3 | Fiducial | Mechanical:Fiducial | Fiducial:Fiducial_0.75mm_Mask1.5mm | ~ |  | DNP
 |  | FID4 | Fiducial | Mechanical:Fiducial | Fiducial:Fiducial_0.75mm_Mask1.5mm | ~ |  | DNP
 |  | FID5 | Fiducial | Mechanical:Fiducial | Fiducial:Fiducial_0.75mm_Mask1.5mm | ~ |  | DNP
 |  | FID6 | Fiducial | Mechanical:Fiducial | Fiducial:Fiducial_0.75mm_Mask1.5mm | ~ |  | DNP
 |  | J1 | USB_C_Receptacle_USB2.0 | Connector:USB_C_Receptacle_USB2.0 | Connector_USB:USB_C_Receptacle_HRO_TYPE-C-31-M-12 | https://www.usb.org/sites/default/files/documents/usb_type-c.zip | GCT | USB4105-GF-A
 |  | J2 | MicroSD | Connector:Conn_01x11_Male | gkl_conn:molex_microsd_1040310811 | ~ | Molex | 1040310811
 |  | J3 | SYZYGY-STD | gkl_misc:SYZYGY-STD | gkl_conn:SYZYGY_standard_carrier |  | Samtec Inc. | QSE-020-01-F-D-A
 |  | J4 | SYZYGY-STD | gkl_misc:SYZYGY-STD | gkl_conn:SYZYGY_standard_carrier |  | Samtec Inc. | QSE-020-01-F-D-A
 |  | J5 | SYZYGY-TXR-4 | gkl_misc:SYZYGY-TXR-4 | gkl_conn:SYZYGY_Transcieiver |  | Samtec Inc. | QSH-020-01-F-D-DP-A
 |  | L3 | 2.2uH | Device:L_Small | Inductor_SMD:L_0805_2012Metric | ~ | Sunltech Tech | SLM20122R2MIT
 |  | L4 | 2.2uH | Device:L_Small | Inductor_SMD:L_0805_2012Metric | ~ | Sunltech Tech | SLM20122R2MIT
 |  | L5 | 2.2uH | Device:L_Small | Inductor_SMD:L_0805_2012Metric | ~ | Sunltech Tech | SLM20122R2MIT
 |  | L6 | 2.2uH | Device:L_Small | Inductor_SMD:L_0805_2012Metric | ~ | Sunltech Tech | SLM20122R2MIT
 |  | L7 | 2.2uH | Device:L_Small | Inductor_SMD:L_0805_2012Metric | ~ | Sunltech Tech | SLM20122R2MIT
 |  | L8 | 2.2uH | Device:L_Small | Inductor_SMD:L_0805_2012Metric | ~ | Sunltech Tech | SLM20122R2MIT
 |  | L9 | 2.2uH | Device:L_Small | Inductor_SMD:L_0805_2012Metric | ~ | Sunltech Tech | SLM20122R2MIT
 |  | L10 | 2.2uH | Device:L_Small | Inductor_SMD:L_0805_2012Metric | ~ | Sunltech Tech | SLM20122R2MIT
 |  | Q1 | Q_NMOS_GSD | Device:Q_NMOS_GSD | Package_TO_SOT_SMD:SOT-323_SC-70 | ~ | Nexperia | 2N7002PW\,115
 |  | Q2 | Q_NMOS_GSD | Device:Q_NMOS_GSD | Package_TO_SOT_SMD:SOT-323_SC-70 | ~ | Nexperia | 2N7002PW\,115
 |  | Q3 | Q_NMOS_GSD | Device:Q_NMOS_GSD | Package_TO_SOT_SMD:SOT-323_SC-70 | ~ | Nexperia | 2N7002PW\,115
 |  | Q4 | Q_NMOS_GSD | Device:Q_NMOS_GSD | Package_SON:Diodes_PowerDI3333-8 | ~ | Diodes Incorporated | DMN6013LFG-7
 |  | R1 | 210k | Device:R | Resistor_SMD:R_0402_1005Metric | ~ | Yageo | RC0402FR-07210KL | 1%
 |  | R2 | 84k5 | Device:R | Resistor_SMD:R_0402_1005Metric | ~ | Yageo | RC0402FR-0784K5L | 1%
 |  | R3 | 49k9 | Device:R | Resistor_SMD:R_0402_1005Metric | ~ | Yageo | RC0402FR-0749K9L | 1%
 |  | R4 | 8.06k | Device:R | Resistor_SMD:R_0402_1005Metric | ~ | Yageo | RC0402FR-078K06L
 |  | R5 | 20K | Device:R | Resistor_SMD:R_0402_1005Metric | ~ | Yageo | RC0402FR-0720KL
 |  | R6 | 5.1k | Device:R | Resistor_SMD:R_0402_1005Metric | ~ | Yageo | RC0402FR-075K1L
 |  | R7 | 5.1k | Device:R | Resistor_SMD:R_0402_1005Metric | ~ | Yageo | RC0402FR-075K1L
 |  | R8 | 1K5 | Device:R | Resistor_SMD:R_0402_1005Metric | ~ | Yageo | RC0402FR-071K5L
 |  | R9 | 1K5 | Device:R | Resistor_SMD:R_0402_1005Metric | ~ | Yageo | RC0402FR-071K5L
 |  | R10 | DNP | Device:R | Resistor_SMD:R_0402_1005Metric | ~ |  | DNP
 |  | R11 | DNP | Device:R | Resistor_SMD:R_0402_1005Metric | ~ |  | DNP
 |  | R12 | 1K5 | Device:R | Resistor_SMD:R_0402_1005Metric | ~ | Yageo | RC0402FR-071K5L
 |  | R13 | 1K5 | Device:R | Resistor_SMD:R_0402_1005Metric | ~ | Yageo | RC0402FR-071K5L
 |  | R14 | 1K5 | Device:R | Resistor_SMD:R_0402_1005Metric | ~ | Yageo | RC0402FR-071K5L
 |  | R15 | 1K5 | Device:R | Resistor_SMD:R_0402_1005Metric | ~ | Yageo | RC0402FR-071K5L
 |  | R16 | 1K5 | Device:R | Resistor_SMD:R_0402_1005Metric | ~ | Yageo | RC0402FR-071K5L
 |  | R17 | 1K5 | Device:R | Resistor_SMD:R_0402_1005Metric | ~ | Yageo | RC0402FR-071K5L
 |  | R18 | 1K5 | Device:R | Resistor_SMD:R_0402_1005Metric | ~ | Yageo | RC0402FR-071K5L
 |  | R19 | 1K5 | Device:R | Resistor_SMD:R_0402_1005Metric | ~ | Yageo | RC0402FR-071K5L
 |  | R20 | DNP | Device:R | Resistor_SMD:R_0402_1005Metric | ~ |  | DNP
 |  | R21 | DNP | Device:R | Resistor_SMD:R_0402_1005Metric | ~ |  | DNP
 |  | R22 | 1K5 | Device:R | Resistor_SMD:R_0402_1005Metric | ~ | Yageo | RC0402FR-071K5L
 |  | R23 | 1K5 | Device:R | Resistor_SMD:R_0402_1005Metric | ~ | Yageo | RC0402FR-071K5L
 |  | R24 | DNP | Device:R | Resistor_SMD:R_0402_1005Metric | ~ |  | DNP
 |  | R25 | DNP | Device:R | Resistor_SMD:R_0402_1005Metric | ~ |  | DNP
 |  | R26 | DNP | Device:R | Resistor_SMD:R_0402_1005Metric | ~ |  | DNP
 |  | R27 | DNP | Device:R | Resistor_SMD:R_0402_1005Metric | ~ |  | DNP
 |  | R28 | DNP | Device:R | Resistor_SMD:R_0402_1005Metric | ~ |  | DNP
 |  | R29 | DNP | Device:R | Resistor_SMD:R_0402_1005Metric | ~ |  | DNP
 |  | R30 | 12.1K | Device:R | Resistor_SMD:R_0402_1005Metric | ~ | Yageo | RC0402FR-0712K1L
 |  | R31 | 220R | Device:R | Resistor_SMD:R_0402_1005Metric | ~ | Yageo | RC0402FR-07220RL
 |  | R32 | 220R | Device:R | Resistor_SMD:R_0402_1005Metric | ~ | Yageo | RC0402FR-07220RL
 |  | R33 | 10K | Device:R | Resistor_SMD:R_0402_1005Metric | ~ | Yageo | RC0402FR-0710KL
 |  | R34 | 10K | Device:R | Resistor_SMD:R_0402_1005Metric | ~ | Yageo | RC0402FR-0710KL
 |  | R35 | 220R | Device:R | Resistor_SMD:R_0402_1005Metric | ~ | Yageo | RC0402FR-07220RL
 |  | R36 | 220R | Device:R | Resistor_SMD:R_0402_1005Metric | ~ | Yageo | RC0402FR-07220RL
 |  | R37 | 10K | Device:R | Resistor_SMD:R_0402_1005Metric | ~ | Yageo | RC0402FR-0710KL
 |  | R38 | 220R | Device:R | Resistor_SMD:R_0402_1005Metric | ~ | Yageo | RC0402FR-07220RL
 |  | R39 | 220R | Device:R | Resistor_SMD:R_0402_1005Metric | ~ | Yageo | RC0402FR-07220RL
 |  | R40 | 10K | Device:R | Resistor_SMD:R_0402_1005Metric | ~ | Yageo | RC0402FR-0710KL
 |  | R41 | 220R | Device:R | Resistor_SMD:R_0402_1005Metric | ~ | Yageo | RC0402FR-07220RL
 |  | R42 | 220R | Device:R | Resistor_SMD:R_0402_1005Metric | ~ | Yageo | RC0402FR-07220RL
 |  | R43 | 10K | Device:R | Resistor_SMD:R_0402_1005Metric | ~ | Yageo | RC0402FR-0710KL
 |  | R44 | 220R | Device:R | Resistor_SMD:R_0402_1005Metric | ~ | Yageo | RC0402FR-07220RL
 |  | R45 | 4k7 | Device:R | Resistor_SMD:R_0402_1005Metric | ~ | Yageo | RC0402FR-074K7L
 |  | R46 | DNP | Device:R | Resistor_SMD:R_0402_1005Metric | ~ |  | DNP
 |  | R47 | 1K | Device:R | Resistor_SMD:R_0402_1005Metric | ~ | Yageo | RC0402FR-071KL
 |  | R48 | 1K | Device:R | Resistor_SMD:R_0402_1005Metric | ~ | Yageo | RC0402FR-071KL
 |  | R49 | DNP | Device:R | Resistor_SMD:R_0402_1005Metric | ~ |  | DNP
 |  | R50 | DNP | Device:R | Resistor_SMD:R_0402_1005Metric | ~ |  | DNP
 |  | R51 | 1K | Device:R | Resistor_SMD:R_0402_1005Metric | ~ | Yageo | RC0402FR-071KL
 |  | R52 | 51R | Device:R | Resistor_SMD:R_0402_1005Metric | ~ | Yageo | RC0402FR-0751RL
 |  | R53 | 10k | Device:R | Resistor_SMD:R_0402_1005Metric | ~ | Yageo | RC0402FR-0710KL
 |  | R54 | 20R | Device:R | Resistor_SMD:R_0402_1005Metric | ~ | Yageo | RC0402FR-0720RL
 |  | R55 | 4k7 | Device:R | Resistor_SMD:R_0402_1005Metric | ~ | Yageo | RC0402FR-074K7L
 |  | R56 | 124k | Device:R | Resistor_SMD:R_0402_1005Metric | ~ | Yageo | RC0402FR-07124KL | 1%
 |  | R57 | 100k | Device:R | Resistor_SMD:R_0402_1005Metric | ~ | Yageo | RC0402FR-07100KL | 1%
 |  | R58 | 316k | Device:R | Resistor_SMD:R_0402_1005Metric | ~ | Yageo | RC0402FR-07316KL | 1%
 |  | R59 | 100k | Device:R | Resistor_SMD:R_0402_1005Metric | ~ | Yageo | RC0402FR-07100KL | 1%
 |  | R60 | 118k | Device:R | Resistor_SMD:R_0402_1005Metric | ~ | Yageo | RC0402FR-07118KL | 1%
 |  | R61 | 210k | Device:R | Resistor_SMD:R_0402_1005Metric | ~ | Yageo | RC0402FR-07210KL | 1%
 |  | R62 | 47k | Device:R | Resistor_SMD:R_0402_1005Metric | ~ | Yageo | RC0402FR-0747KL
 |  | R63 | 100k | Device:R | Resistor_SMD:R_0402_1005Metric | ~ | Yageo | RC0402FR-07100KL | 1%
 |  | R64 | 100k | Device:R | Resistor_SMD:R_0402_1005Metric | ~ | Yageo | RC0402FR-07100KL | 1%
 |  | R65 | 100k | Device:R | Resistor_SMD:R_0402_1005Metric | ~ | Yageo | RC0402FR-07100KL | 1%
 |  | R66 | 100k | Device:R | Resistor_SMD:R_0402_1005Metric | ~ | Yageo | RC0402FR-07100KL | 1%
 |  | R67 | 51R | Device:R | Resistor_SMD:R_0402_1005Metric | ~ | Yageo | RC0402FR-0751RL
 |  | R68 | 240R | Device:R | Resistor_SMD:R_0402_1005Metric | ~ | Yageo | RC0402FR-07240RL
 |  | R69 | 1K | Device:R | Resistor_SMD:R_0402_1005Metric | ~ | Yageo | RC0402FR-071KL
 |  | R70 | 1K | Device:R | Resistor_SMD:R_0402_1005Metric | ~ | Yageo | RC0402FR-071KL
 |  | R71 | 51R | Device:R | Resistor_SMD:R_0402_1005Metric | ~ | Yageo | RC0402FR-0751RL
 |  | R72 | 240R | Device:R | Resistor_SMD:R_0402_1005Metric | ~ | Yageo | RC0402FR-07240RL
 |  | R73 | 100k | Device:R | Resistor_SMD:R_0402_1005Metric | ~ | Yageo | RC0402FR-07100KL | 1%
 |  | R74 | 118k | Device:R | Resistor_SMD:R_0402_1005Metric | ~ | Yageo | RC0402FR-07118KL | 1%
 |  | R75 | 34.0K | Device:R | Resistor_SMD:R_0402_1005Metric | ~ | Yageo | RC0402FR-0734KL | 1%
 |  | R76 | 10K | Device:R | Resistor_SMD:R_0402_1005Metric | ~ | Yageo | RC0402FR-0710KL
 |  | R77 | 34.0K | Device:R | Resistor_SMD:R_0402_1005Metric | ~ | Yageo | RC0402FR-0734KL | 1%
 |  | R78 | 53.6K | Device:R | Resistor_SMD:R_0402_1005Metric | ~ | Yageo | RC0402FR-0753K6L | 1%
 |  | R79 | 13.0K | Device:R | Resistor_SMD:R_0402_1005Metric | ~ | Yageo | RC0402FR-0713KL | 1%
 |  | R80 | 34.0K | Device:R | Resistor_SMD:R_0402_1005Metric | ~ | Yageo | RC0402FR-0734KL | 1%
 |  | R81 | 10K | Device:R | Resistor_SMD:R_0402_1005Metric | ~ | Yageo | RC0402FR-0710KL
 |  | R82 | 34.0K | Device:R | Resistor_SMD:R_0402_1005Metric | ~ | Yageo | RC0402FR-0734KL | 1%
 |  | R83 | 53.6K | Device:R | Resistor_SMD:R_0402_1005Metric | ~ | Yageo | RC0402FR-0753K6L | 1%
 |  | R84 | 13.0K | Device:R | Resistor_SMD:R_0402_1005Metric | ~ | Yageo | RC0402FR-0713KL | 1%
 |  | R85 | 34.0K | Device:R | Resistor_SMD:R_0402_1005Metric | ~ | Yageo | RC0402FR-0734KL | 1%
 |  | R86 | 10K | Device:R | Resistor_SMD:R_0402_1005Metric | ~ | Yageo | RC0402FR-0710KL
 |  | R87 | 34.0K | Device:R | Resistor_SMD:R_0402_1005Metric | ~ | Yageo | RC0402FR-0734KL | 1%
 |  | R88 | 53.6K | Device:R | Resistor_SMD:R_0402_1005Metric | ~ | Yageo | RC0402FR-0753K6L | 1%
 |  | R89 | 13.0K | Device:R | Resistor_SMD:R_0402_1005Metric | ~ | Yageo | RC0402FR-0713KL | 1%
 |  | R90 | 100k | Device:R | Resistor_SMD:R_0402_1005Metric | ~ | Yageo | RC0402FR-07100KL | 1%
 |  | R91 | 23.7k | Device:R | Resistor_SMD:R_0402_1005Metric | ~ | Yageo | RC0402FR-0723K7L | 1%
 |  | R92 | 5.1k | Device:R | Resistor_SMD:R_0402_1005Metric | ~ | Yageo | RC0402FR-075K1L
 |  | R93 | 51R | Device:R | Resistor_SMD:R_0402_1005Metric | ~ | Yageo | RC0402FR-0751RL
 |  | R94 | 51R | Device:R | Resistor_SMD:R_0402_1005Metric | ~ | Yageo | RC0402FR-0751RL
 |  | R95 | 23.7k | Device:R | Resistor_SMD:R_0402_1005Metric | ~ | Yageo | RC0402FR-0723K7L | 1%
 |  | R96 | 5.1k | Device:R | Resistor_SMD:R_0402_1005Metric | ~ | Yageo | RC0402FR-075K1L
 |  | R97 | 47k | Device:R | Resistor_SMD:R_0402_1005Metric | ~ | Yageo | RC0402FR-0747KL
 |  | SW1 | SW_Push | Switch:SW_Push | Button_Switch_SMD:SW_SPST_PTS810 | ~ | C&K | PTS810SJK250SMTRLFS
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

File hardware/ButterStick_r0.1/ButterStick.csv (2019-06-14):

Source: | /home/greg/projects/ButterStick/hardware/ButterStick/ButterStick.sch
Date: | Thu 21 Mar 2019 17:45:17 ACDT
Tool: | Eeschema 5.1.0-060a0da~80~ubuntu18.04.1
Generator: | /usr/share/kicad/plugins/bom_csv_grouped_by_value.py
Component Count: | 181
Individual Components:
Item | Qty | Reference(s) | Value | LibPart | Footprint | Datasheet | MFG | Mfg | PN | SN-DK | Tol
 |  | C1 | 4.7uF | Device:C | pkl_dipol:C_0603 | ~ |  | Samsung Electro-Mechanics | CL10A475KP8NNNC
 |  | C2 | 100nF | Device:C | pkl_dipol:C_0402 | ~ |  | Samsung Electro-Mechanics | CL05B104KP5NNNC
 |  | C3 | 1uF | Device:C | pkl_dipol:C_0402 |  |  | Samsung Electro-Mechanics | CL05A105KP5NNNC | 445-13185-1-ND
 |  | C4 | 1uF | Device:C | pkl_dipol:C_0402 |  |  | Samsung Electro-Mechanics | CL05A105KP5NNNC | 445-13185-1-ND
 |  | C5 | 1uF | Device:C | pkl_dipol:C_0402 |  |  | Samsung Electro-Mechanics | CL05A105KP5NNNC | 445-13185-1-ND
 |  | C6 | 100nF | Device:C | pkl_dipol:C_0402 |  |  |  | CL05B104KP5NNNC | 1276-1002-1-ND
 |  | C7 | 100nF | Device:C | pkl_dipol:C_0402 |  |  |  | CL05B104KP5NNNC | 1276-1002-1-ND
 |  | C8 | 100nF | Device:C | pkl_dipol:C_0402 |  |  |  | CL05B104KP5NNNC | 1276-1002-1-ND
 |  | C9 | 100nF | Device:C | pkl_dipol:C_0402 |  |  |  | CL05B104KP5NNNC | 1276-1002-1-ND
 |  | C10 | 100nF | Device:C | pkl_dipol:C_0402 |  |  |  | CL05B104KP5NNNC | 1276-1002-1-ND
 |  | C11 | 10uF | Device:C | pkl_dipol:C_0603 |  |  |  | CL10A106MP8NNNC | 445-7486-1-ND
 |  | C12 | 4.7uF | Device:C | pkl_dipol:C_0603 | ~ |  | Samsung Electro-Mechanics | CL10A475KP8NNNC
 |  | C13 | 10uF | Device:C | pkl_dipol:C_0603 |  |  |  | CL10A106MP8NNNC | 445-7486-1-ND
 |  | C14 | 10uF | Device:C | pkl_dipol:C_0603 |  |  |  | CL10A106MP8NNNC | 445-7486-1-ND
 |  | C15 | 100nF | Device:C | pkl_dipol:C_0402 |  |  |  | CL05B104KP5NNNC | 1276-1002-1-ND
 |  | C16 | 100nF | Device:C | pkl_dipol:C_0402 |  |  |  | CL05B104KP5NNNC | 1276-1002-1-ND
 |  | C17 | 100nF | Device:C | pkl_dipol:C_0402 |  |  |  | CL05B104KP5NNNC | 1276-1002-1-ND
 |  | C18 | 100nF | Device:C | pkl_dipol:C_0402 |  |  |  | CL05B104KP5NNNC | 1276-1002-1-ND
 |  | C19 | 100nF | Device:C | pkl_dipol:C_0402 |  |  |  | CL05B104KP5NNNC | 1276-1002-1-ND
 |  | C20 | 100nF | Device:C | pkl_dipol:C_0402 |  |  |  | CL05B104KP5NNNC | 1276-1002-1-ND
 |  | C21 | 100nF | Device:C | pkl_dipol:C_0402 |  |  |  | CL05B104KP5NNNC | 1276-1002-1-ND
 |  | C22 | 100nF | Device:C | pkl_dipol:C_0402 |  |  |  | CL05B104KP5NNNC | 1276-1002-1-ND
 |  | C23 | 100nF | Device:C | pkl_dipol:C_0402 |  |  |  | CL05B104KP5NNNC | 1276-1002-1-ND
 |  | C24 | 4.7uF | Device:C | pkl_dipol:C_0603 | ~ |  | Samsung Electro-Mechanics | CL10A475KP8NNNC
 |  | C25 | 100nF | Device:C | pkl_dipol:C_0402 | ~ |  | Samsung Electro-Mechanics | CL05B104KP5NNNC
 |  | C26 | 100nF | Device:C | pkl_dipol:C_0402 | ~ |  | Samsung Electro-Mechanics | CL05B104KP5NNNC
 |  | C27 | 100nF | Device:C | pkl_dipol:C_0402 | ~ |  | Samsung Electro-Mechanics | CL05B104KP5NNNC
 |  | C28 | 100nF | Device:C | pkl_dipol:C_0402 | ~ |  | Samsung Electro-Mechanics | CL05B104KP5NNNC
 |  | C29 | 100nF | Device:C | pkl_dipol:C_0402 | ~ |  | Samsung Electro-Mechanics | CL05B104KP5NNNC
 |  | C30 | 100nF | Device:C | pkl_dipol:C_0402 | ~ |  | Samsung Electro-Mechanics | CL05B104KP5NNNC
 |  | C31 | 100nF | Device:C | pkl_dipol:C_0402 | ~ |  | Samsung Electro-Mechanics | CL05B104KP5NNNC
 |  | C32 | 100nF | Device:C | pkl_dipol:C_0402 | ~ |  | Samsung Electro-Mechanics | CL05B104KP5NNNC
 |  | C33 | 100nF | Device:C | pkl_dipol:C_0402 | ~ |  | Samsung Electro-Mechanics | CL05B104KP5NNNC
 |  | C34 | 100nF | Device:C | pkl_dipol:C_0402 | ~ |  | Samsung Electro-Mechanics | CL05B104KP5NNNC
 |  | C35 | 100nF | Device:C | pkl_dipol:C_0402 | ~ |  | Samsung Electro-Mechanics | CL05B104KP5NNNC
 |  | C36 | 22pF | Device:C | pkl_dipol:C_0402 | ~ |  | Samsung Electro-Mechanics | CL05C220JB5NNWC
 |  | C37 | 22pF | Device:C | pkl_dipol:C_0402 | ~ |  | Samsung Electro-Mechanics | CL05C220JB5NNWC
 |  | C38 | 4.7uF | Device:C | pkl_dipol:C_0603 | ~ |  | Samsung Electro-Mechanics | CL10A475KP8NNNC
 |  | C39 | 100nF | Device:C | pkl_dipol:C_0402 | ~ |  | Samsung Electro-Mechanics | CL05B104KP5NNNC
 |  | C40 | 4.7uF | Device:C | pkl_dipol:C_0603 | ~ |  | Samsung Electro-Mechanics | CL10A475KP8NNNC | 1276-1044-1-ND
 |  | C41 | 4.7uF | Device:C | pkl_dipol:C_0603 | ~ |  | Samsung Electro-Mechanics | CL10A475KP8NNNC | 1276-1044-1-ND
 |  | C42 | 4.7uF | Device:C | pkl_dipol:C_0603 | ~ |  | Samsung Electro-Mechanics | CL10A475KP8NNNC
 |  | C43 | 4.7uF | Device:C | pkl_dipol:C_0603 | ~ |  | Samsung Electro-Mechanics | CL10A475KP8NNNC
 |  | C44 | 100nF | Device:C | pkl_dipol:C_0402 | ~ |  | Samsung Electro-Mechanics | CL05B104KP5NNNC
 |  | C45 | 4.7uF | Device:C | pkl_dipol:C_0603 | ~ |  | Samsung Electro-Mechanics | CL10A475KP8NNNC
 |  | C46 | 100nF | Device:C | pkl_dipol:C_0402 | ~ |  | Samsung Electro-Mechanics | CL05B104KP5NNNC
 |  | C47 | 4.7uF | Device:C | pkl_dipol:C_0603 | ~ |  | Samsung Electro-Mechanics | CL10A475KP8NNNC
 |  | C48 | 100nF | Device:C | pkl_dipol:C_0402 |  |  |  | CL05B104KP5NNNC | 1276-1002-1-ND
 |  | C49 | 100nF | Device:C | pkl_dipol:C_0402 |  |  |  | CL05B104KP5NNNC | 1276-1002-1-ND
 |  | C50 | 100nF | Device:C | pkl_dipol:C_0402 | ~ |  | Samsung Electro-Mechanics | CL05B104KP5NNNC
 |  | C51 | 1uF | Device:C | pkl_dipol:C_0402 |  |  | Samsung Electro-Mechanics | CL05A105KP5NNNC | 1276-1002-1-ND
 |  | C52 | 22uF | Device:C | pkl_dipol:C_0805 |  |  |  | CL21A226MOCLRNC | 1276-1002-1-ND
 |  | C53 | 22uF | Device:C | pkl_dipol:C_0805 |  |  |  | CL21A226MOCLRNC | 1276-1002-1-ND
 |  | C54 | 22uF | Device:C | pkl_dipol:C_0805 |  |  |  | CL21A226MOCLRNC | 1276-1002-1-ND
 |  | C55 | 10uF | Device:C | pkl_dipol:C_0603 | ~ |  |  | CL10A106MP8NNNC | 445-7486-1-ND
 |  | C56 | 22uF | Device:C | pkl_dipol:C_0805 |  |  |  | CL21A226MOCLRNC | 1276-1002-1-ND
 |  | C57 | 10pF | Device:C | pkl_dipol:C_0402 |  |  |  | CL05C100JB5NNNC | 1276-1002-1-ND
 |  | C58 | 10nF | Device:C | pkl_dipol:C_0402 |  |  | Samsung Electro-Mechanics | CL05B103KB5NNNC | 1276-1002-1-ND
 |  | C59 | 10nF | Device:C | pkl_dipol:C_0402 |  |  | Samsung Electro-Mechanics | CL05B103KB5NNNC | 1276-1002-1-ND
 |  | C60 | 10pF | Device:C | pkl_dipol:C_0402 |  |  |  | CL05C100JB5NNNC | 1276-1002-1-ND
 |  | C61 | 10nF | Device:C | pkl_dipol:C_0402 | ~ |  | Samsung Electro-Mechanics | CL05B103KB5NNNC
 |  | C62 | 10nF | Device:C | pkl_dipol:C_0402 | ~ |  | Samsung Electro-Mechanics | CL05B103KB5NNNC
 |  | C63 | 10nF | Device:C | pkl_dipol:C_0402 | ~ |  | Samsung Electro-Mechanics | CL05B103KB5NNNC
 |  | C64 | 100nF | Device:C | pkl_dipol:C_0402 |  |  |  | CL05B104KP5NNNC | 1276-1002-1-ND
 |  | C65 | 100nF | Device:C | pkl_dipol:C_0402 |  |  |  | CL05B104KP5NNNC | 1276-1002-1-ND
 |  | C66 | 100nF | Device:C | pkl_dipol:C_0402 |  |  |  | CL05B104KP5NNNC | 1276-1002-1-ND
 |  | C67 | 10uF | Device:C | pkl_dipol:C_0805 |  |  |  | CL21A106KAFN3NE
 |  | C68 | 100n | Device:C | pkl_dipol:C_0603 |  |  |  | CL10B104KB8NNNC
 |  | C69 | 10uF | Device:C | pkl_dipol:C_0805 |  |  |  | CL21A106KAFN3NE
 |  | C70 | 10uF | Device:C | pkl_dipol:C_0805 |  |  |  | CL21A106KAFN3NE
 |  | C71 | 100nF | Device:C | pkl_dipol:C_0402 | ~ |  | Samsung Electro-Mechanics | CL05B104KP5NNNC
 |  | CON1 | JD1_0001NL | gkl_misc:JD1_0001NL | gkl_conn:MAGJACK |  |  |  | JD1-0001NL | 553-2361-ND
 |  | D1 | pkl_LED | pkl_device:pkl_LED | pkl_dipol:D_0603 |  |  | Lite-On Inc. | LTST-C190GKT
 |  | D2 | pkl_LED | pkl_device:pkl_LED | pkl_dipol:D_0603 |  |  | Lite-On Inc. | LTST-C190GKT
 |  | D3 | pkl_LED | pkl_device:pkl_LED | pkl_dipol:D_0603 |  |  | Lite-On Inc. | LTST-C190GKT
 |  | D4 | pkl_LED | pkl_device:pkl_LED | pkl_dipol:D_0603 |  |  | Lite-On Inc. | LTST-C190GKT
 |  | D5 | pkl_LED | pkl_device:pkl_LED | pkl_dipol:D_0603 |  |  | Lite-On Inc. | LTST-C190GKT
 |  | D6 | pkl_LED | pkl_device:pkl_LED | pkl_dipol:D_0603 |  |  | Lite-On Inc. | LTST-C190GKT
 |  | D7 | pkl_LED | pkl_device:pkl_LED | pkl_dipol:D_0603 |  |  | Lite-On Inc. | LTST-C190GKT
 |  | D8 | pkl_LED | pkl_device:pkl_LED | pkl_dipol:D_0603 |  |  | Lite-On Inc. | LTST-C190GKT
 |  | D9 | pkl_LED | pkl_device:pkl_LED | pkl_dipol:D_0603 |  |  | Lite-On Inc. | LTST-C190GKT
 |  | FB1 | 600R | Device:Ferrite_Bead_Small | pkl_dipol:L_0402 | ~ |  | Samsung Electro-Mechanics | CIM05U601NC
 |  | FB2 | 600R | Device:Ferrite_Bead_Small | pkl_dipol:L_0402 | ~ |  | Samsung Electro-Mechanics | CIM05U601NC
 |  | J1 | SYZYGY-STD | gkl_misc:SYZYGY-STD | gkl_conn:SYZYGY_standard_carrier |  |  | Samtec Inc. | QSE-020-01-F-D-A
 |  | J2 | JST GH Series | Connector:Conn_01x06_Male | Connectors_JST:JST_GH_BM06B-GHS-TBT_06x1.25mm_Straight | ~ |  |  | BM06B-GHS-TBT(LF)(SN)(N) | 455-1582-1-ND
 |  | J3 | SYZYGY-STD | gkl_misc:SYZYGY-STD | gkl_conn:SYZYGY_standard_carrier |  |  | Samtec Inc. | QSE-020-01-F-D-A
 |  | J4 | MicroSD | Connector:Conn_01x11_Male | gkl_conn:molex_microsd_1040310811 | ~ |  |  | 1040310811 | WM6357CT-ND
 |  | J5 | SYZYGY-STD | gkl_misc:SYZYGY-STD | gkl_conn:SYZYGY_standard_carrier |  |  | Samtec Inc. | QSE-020-01-F-D-A
 |  | J6 | JST_PA | Connector:Conn_01x02_Male | gkl_conn:SB02B-PASK-2 | ~ |  | JST Sales America Inc. | S02B-PASK-2(LF)(SN)
 |  | J7 | TagConnect | Connector_Generic:Conn_02x03_Odd_Even | pkl_tag_connect:TC2030-NL_SMALL | ~
 |  | L1 | 600R | Device:Ferrite_Bead_Small | pkl_dipol:L_0402 | ~ |  | Samsung Electro-Mechanics | CIM05U601NC | 490-1006-1-ND
 |  | L2 | 2.2uH | Device:L_Small | Inductor_SMD:L_Taiyo-Yuden_MD-5050 | ~ | Taiyo Yuden |  | NR5040T2R2N
 |  | L3 | 600R | Device:Ferrite_Bead_Small | pkl_dipol:L_0603 | ~ |  |  | 742792651 | 732-1593-1-ND
 |  | L4 | 2.2uH | Device:L_Small | Inductor_SMD:L_Taiyo-Yuden_MD-5050 | ~ | Taiyo Yuden |  | NR5040T2R2N
 |  | R1 | 42k2 | Device:R | pkl_dipol:C_0402 | ~ |  | Stackpole Electronics Inc | RNCF0402DTE42K2 |  | 0.5%
 |  | R2 | 33K | Device:R | pkl_dipol:C_0402 | ~ |  | Stackpole Electronics Inc | RNCF0402DTE33K0 |  | 0.5%
 |  | R3 | 1k | Device:R | pkl_dipol:R_0402 |  |  |  | RC0402JR-071KL | 311-1.0KJRCT-ND
 |  | R4 | 10k | Device:R | pkl_dipol:R_0402 |  |  | Stackpole Electronics Inc | RMCF0402FT10K0 | P10KDECT-ND
 |  | R5 | 24k9 | Device:R | pkl_dipol:C_0402 | ~ |  | Stackpole Electronics Inc | RNCF0402DTE24K9 |  | 0.5%
 |  | R6 | 42k2 | Device:R | pkl_dipol:C_0402 | ~ |  | Stackpole Electronics Inc | RNCF0402DTE42K2 |  | 0.5%
 |  | R7 | 1k5 | Device:R | pkl_dipol:R_0402 | ~ |  |  | RC0402FR-071K5L | 311-1.50KLRCT-ND
 |  | R8 | 1k5 | Device:R | pkl_dipol:R_0402 | ~ |  |  | RC0402FR-071K5L | 311-1.50KLRCT-ND
 |  | R9 | 1k5 | Device:R | pkl_dipol:R_0402 | ~ |  |  | RC0402FR-071K5L | 311-1.50KLRCT-ND
 |  | R10 | 1k5 | Device:R | pkl_dipol:R_0402 | ~ |  |  | RC0402FR-071K5L | 311-1.50KLRCT-ND
 |  | R11 | 1k5 | Device:R | pkl_dipol:R_0402 | ~ |  |  | RC0402FR-071K5L | 311-1.50KLRCT-ND
 |  | R12 | 1k5 | Device:R | pkl_dipol:R_0402 | ~ |  |  | RC0402FR-071K5L | 311-1.50KLRCT-ND
 |  | R13 | 1k5 | Device:R | pkl_dipol:R_0402 | ~ |  |  | RC0402FR-071K5L | 311-1.50KLRCT-ND
 |  | R14 | 1k5 | Device:R | pkl_dipol:R_0402 | ~ |  |  | RC0402FR-071K5L | 311-1.50KLRCT-ND
 |  | R15 | 1k5 | Device:R | pkl_dipol:R_0402 | ~ |  |  | RC0402FR-071K5L | 311-1.50KLRCT-ND
 |  | R16 | 33K | Device:R | pkl_dipol:C_0402 | ~ |  | Stackpole Electronics Inc | RNCF0402DTE33K0 |  | 0.5%
 |  | R17 | 24k9 | Device:R | pkl_dipol:C_0402 | ~ |  | Stackpole Electronics Inc | RNCF0402DTE24K9 |  | 0.5%
 |  | R18 | 42k2 | Device:R | pkl_dipol:C_0402 | ~ |  | Stackpole Electronics Inc | RNCF0402DTE42K2 |  | 0.5%
 |  | R19 | 12.1K | Device:R | pkl_dipol:R_0603 | ~ |  |  | P12.0KHCT-ND | ERJ-3EKF1202V
 |  | R20 | 220R | Device:R | pkl_dipol:R_0402 | ~ |  |  | RC0402JR-07220RL | 311-220JRCT-ND
 |  | R21 | 220R | Device:R | pkl_dipol:R_0402 | ~ |  |  | RC0402JR-07220RL | 311-220JRCT-ND
 |  | R22 | 33K | Device:R | pkl_dipol:C_0402 | ~ |  | Stackpole Electronics Inc | RNCF0402DTE33K0 |  | 0.5%
 |  | R23 | 24k9 | Device:R | pkl_dipol:C_0402 | ~ |  | Stackpole Electronics Inc | RNCF0402DTE24K9 |  | 0.5%
 |  | R24 | 1k5 | Device:R | pkl_dipol:R_0402 | ~ |  |  | RC0402FR-071K5L | 311-1.50KLRCT-ND
 |  | R25 | 210k | Device:R | pkl_dipol:R_0402 | ~ |  | Stackpole Electronics Inc | RMCF0402FT210K |  | 1%
 |  | R26 | 84k5 | Device:R | pkl_dipol:R_0402 | ~ |  | Stackpole Electronics Inc | RMCF0402FT84K5 |  | 1%
 |  | R27 | 2k2 | Device:R | pkl_dipol:R_0402 | ~ |  | Stackpole Electronics Inc | RMCF0402FT2K20
 |  | R28 | 49k9 | Device:R | pkl_dipol:R_0402 | ~ |  | Stackpole Electronics Inc | RMCF0402FT49K9 |  | 1%
 |  | R29 | 0R | Device:R | pkl_dipol:R_0402 | ~ |  | Stackpole Electronics Inc | RMCF0402ZT0R00
 |  | R30 | 0R | Device:R | pkl_dipol:R_0402 | ~ |  | Stackpole Electronics Inc | RMCF0402ZT0R00
 |  | R31 | 0R | Device:R | pkl_dipol:R_0402 | ~ |  | Stackpole Electronics Inc | RMCF0402ZT0R00
 |  | R32 | 2k2 | Device:R | pkl_dipol:R_0402 | ~ |  | Stackpole Electronics Inc | RMCF0402FT2K20
 |  | R33 | 2k2 | Device:R | pkl_dipol:R_0402 | ~ |  | Stackpole Electronics Inc | RMCF0402FT2K20
 |  | R34 | 2k2 | Device:R | pkl_dipol:R_0402 | ~ |  | Stackpole Electronics Inc | RMCF0402FT2K20
 |  | R35 | 1k | Device:R | pkl_dipol:R_0402 |  |  |  | RC0402JR-071KL | 311-1.0KJRCT-ND
 |  | R36 | 1k | Device:R | pkl_dipol:R_0402 |  |  |  | RC0402JR-071KL | 311-1.0KJRCT-ND
 |  | R37 | 1k | Device:R | pkl_dipol:R_0402 |  |  |  | RC0402JR-071KL | 311-1.0KJRCT-ND
 |  | R38 | 1k | Device:R | pkl_dipol:R_0402 |  |  |  | RC0402JR-071KL | 311-1.0KJRCT-ND
 |  | R39 | 1k | Device:R | pkl_dipol:R_0402 |  |  |  | RC0402JR-071KL | 311-1.0KJRCT-ND
 |  | R40 | 1k | Device:R | pkl_dipol:R_0402 |  |  |  | RC0402JR-071KL | 311-1.0KJRCT-ND
 |  | R41 | 1k | Device:R | pkl_dipol:R_0402 |  |  |  | RC0402JR-071KL | 311-1.0KJRCT-ND
 |  | R42 | 1k | Device:R | pkl_dipol:R_0402 |  |  |  | RC0402JR-071KL | 311-1.0KJRCT-ND
 |  | R43 | 124k | Device:R | pkl_dipol:R_0402 | ~ |  | Stackpole Electronics Inc | RMCF0402FT124K
 |  | R44 | 22.1k | Device:R | pkl_dipol:R_0402 | ~ |  | Stackpole Electronics Inc | RMCF0402FT22K1
 |  | R45 | 73.2k | Device:R | pkl_dipol:R_0402 | ~ |  | Stackpole Electronics Inc | RMCF0402FT73K2
 |  | R46 | 22.1k | Device:R | pkl_dipol:R_0402 | ~ |  | Stackpole Electronics Inc | RMCF0402FT22K1
 |  | R47 | 2k2 | Device:R | pkl_dipol:R_0402 | ~ |  | Stackpole Electronics Inc | RMCF0402FT2K20
 |  | R48 | 2k2 | Device:R | pkl_dipol:R_0402 | ~ |  | Stackpole Electronics Inc | RMCF0402FT2K20
 |  | R49 | 2k2 | Device:R | pkl_dipol:R_0402 | ~ |  | Stackpole Electronics Inc | RMCF0402FT2K20
 |  | R50 | 2k2 | Device:R | pkl_dipol:R_0402 | ~ |  | Stackpole Electronics Inc | RMCF0402FT2K20
 |  | R51 | 2k2 | Device:R | pkl_dipol:R_0402 | ~ |  | Stackpole Electronics Inc | RMCF0402FT2K20
 |  | R52 | 2k2 | Device:R | pkl_dipol:R_0402 | ~ |  | Stackpole Electronics Inc | RMCF0402FT2K20
 |  | R53 | 0R | Device:R | pkl_dipol:R_0402 | ~ |  | Stackpole Electronics Inc | RMCF0402ZT0R00
 |  | R54 | 0R | Device:R | pkl_dipol:R_0402 | ~ |  | Stackpole Electronics Inc | RMCF0402ZT0R00
 |  | R55 | 0R | Device:R | pkl_dipol:R_0402 | ~ |  | Stackpole Electronics Inc | RMCF0402ZT0R00
 |  | R56 | 124k | Device:R | pkl_dipol:R_0402 | ~ |  | Stackpole Electronics Inc | RMCF0402FT124K
 |  | R57 | 124k | Device:R | pkl_dipol:R_0402 | ~ |  | Stackpole Electronics Inc | RMCF0402FT124K
 |  | R58 | 124k | Device:R | pkl_dipol:R_0402 | ~ |  | Stackpole Electronics Inc | RMCF0402FT124K
 |  | R59 | 510k | Device:R | pkl_dipol:R_0402 | ~ |  | Stackpole Electronics Inc | RMCF0402FT510K
 |  | R60 | 2k2 | Device:R | pkl_dipol:R_0402 | ~ |  | Stackpole Electronics Inc | RMCF0402FT2K20
 |  | R61 | 10k | Device:R | pkl_dipol:R_0402 | ~ |  | Stackpole Electronics Inc | RMCF0402FT10K0
 |  | R62 | 10k | Device:R | pkl_dipol:R_0402 | ~ |  | Stackpole Electronics Inc | RMCF0402FT10K0
 |  | U1 | TLV725P | gkl_pmic:NCP167 | bosonFrameGrabber:X2SON | http://www.onsemi.com/pub/Collateral/NCP167-D.PDF |  | Texas Instruments | TLV73325PDQNT | 296-38493-1-ND
 |  | U2 | DAC081C081CIMK | Analog_DAC:DAC081C081CIMK | Package_TO_SOT_SMD:SOT-23-6 | http://www.ti.com/lit/ds/symlink/dac081c081.pdf |  | Texas Instruments | DAC081C081CIMK/NOPB
 |  | U3 | ECP5U25 | gkl_lattice:ECP5U25-BG381 | gkl_housings_bga:caBGA_381_17x17 |  |  | Lattice | LFE5U-45F-8BG381C | 220-2052-ND
 |  | U4 | IS66WVH16M8ALL | gkl_mem:S27KS0641 | bosonFrameGrabber:BGA_24 |  |  | ISSI, Integrated Silicon Solution Inc | IS66WVH16M8ALL-166B1LI | 706-1548-ND
 |  | U5 | IS66WVH16M8ALL | gkl_mem:S27KS0641 | bosonFrameGrabber:BGA_24 |  |  | ISSI, Integrated Silicon Solution Inc | IS66WVH16M8ALL-166B1LI | 706-1548-ND
 |  | U6 | S25FL127S | gkl_mem:AT25SF081 | Package_SO:SOIJ-8_5.3x5.3mm_P1.27mm |  |  | Cypress Semiconductor Corp | S25FL127SABMFI101 | 1092-1178-1-ND
 |  | U7 | TPS73101DBV | Regulator_Linear:TPS73101DBV | Package_TO_SOT_SMD:SOT-23-5 | http://www.ti.com/lit/ds/symlink/tps731.pdf |  | Texas Instruments | TPS73101DBVR
 |  | U8 | TLV718P | gkl_pmic:NCP167 | bosonFrameGrabber:X2SON | http://www.onsemi.com/pub/Collateral/NCP167-D.PDF |  | Texas Instruments | TLV73318PDQNT | 296-38538-1-ND
 |  | U9 | TLV711P | gkl_pmic:NCP167 | bosonFrameGrabber:X2SON | http://www.onsemi.com/pub/Collateral/NCP167-D.PDF |  | Texas Instruments | TLV73311PDQNT | 296-38619-1-ND
 |  | U10 | XCL206 | gkl_pmic:XCL206 | bosonFrameGrabber:CL-2025 |  |  | Torex Semiconductor Ltd | XCL206B123CR-G | 893-1404-1-ND
 |  | U11 | KSZ9031 | gkl_microchip:KSZ9031 | Housings_DFN_QFN:QFN-48-1EP_7x7mm_Pitch0.5mm |  | Microchip Technology |  | KSZ9031RNXCA | 576-4040-ND
 |  | U12 | DAC081C081CIMK | Analog_DAC:DAC081C081CIMK | Package_TO_SOT_SMD:SOT-23-6 | http://www.ti.com/lit/ds/symlink/dac081c081.pdf |  | Texas Instruments | DAC081C081CIMK/NOPB
 |  | U13 | SN74LVC1T45 | gkl_misc:SN74LVC1T45 | TO_SOT_Packages_SMD:SOT-666 |  |  | Texas Instruments | SN74LVC1T45DRLR | 296-20629-1-ND
 |  | U14 | SN74LVC1T45 | gkl_misc:SN74LVC1T45 | TO_SOT_Packages_SMD:SOT-666 |  |  | Texas Instruments | SN74LVC1T45DRLR | 296-20629-1-ND
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

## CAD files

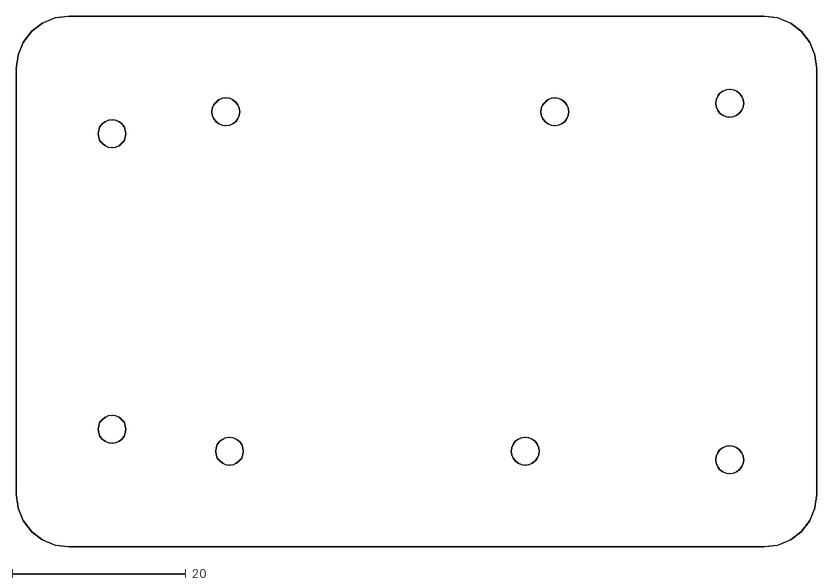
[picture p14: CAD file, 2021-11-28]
mechanical/case/acrylic_plate/butterstick_acrylic_plate.dxf
92.0 x 61.0

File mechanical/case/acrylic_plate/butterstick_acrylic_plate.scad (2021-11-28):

hole_diameter = 3.2;

porta_left_hole_x = 112.5;
porta_left_hole_y = 88.7;

porta_right_hole_x = 112.5;
porta_right_hole_y = 122.7;

portb_left_hole_x = 160;
portb_left_hole_y = 86.2;

portb_right_hole_x = 126;
portb_right_hole_y = 86.2;

portc_left_hole_x = 125.59;
portc_left_hole_y = 125.2;

portc_right_hole_x = 163.41;
portc_right_hole_y = 125.2;

mount_hole_left_x = 183.5;
mount_hole_left_y = 126.2;

mount_hole_right_x = 183.5;
mount_hole_right_y = 85.2;

board_edge_min_x = 107.5;
board_edge_min_y = 81.2;
board_edge_max_x = 187.5;
board_edge_max_y = 130.2;

board_size_x = board_edge_max_x-board_edge_min_x;
board_size_y = board_edge_max_y-board_edge_min_y;
board_centre_x = board_edge_min_x + board_size_x/2;
board_centre_y = board_edge_min_y + board_size_y/2;

echo ("board size is ", board_size_x, " by ", board_size_y);
echo ("board centre is ", board_centre_x, " & ", board_centre_y);

margin=6;

module hole(x,y) {
    echo (" hole at ", x, " by ", y);
    translate([x-board_centre_x, y-board_centre_y]) circle(d=hole_diameter, $fn=24);
}

difference() {
    hull() {
        translate([+board_size_x/2, +board_size_y/2]) circle(r=margin, $fn=24);
        translate([+board_size_x/2, -board_size_y/2]) circle(r=margin, $fn=24);
        translate([-board_size_x/2, +board_size_y/2]) circle(r=margin, $fn=24);
        translate([-board_size_x/2, -board_size_y/2]) circle(r=margin, $fn=24);
    }

    hole(porta_left_hole_x, porta_left_hole_y);
    hole(porta_right_hole_x, porta_right_hole_y);
    hole(portb_left_hole_x, portb_left_hole_y);
    hole(portb_right_hole_x, portb_right_hole_y);
    hole(portc_left_hole_x, portc_left_hole_y);
    hole(portc_right_hole_x, portc_right_hole_y);
    hole(mount_hole_left_x, mount_hole_left_y);
    hole(mount_hole_right_x, mount_hole_right_y);
}
        

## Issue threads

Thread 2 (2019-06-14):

1.1V regulator choice is difficult to source

gregdavill, 2019-06-14:
The FPGA's VCC regulator should supply 1.1V.

The current consumption on this line varies with device densities, but ranges from 77mA on the 12F to 212mA on the 85F.

I selected the 1.1V variant of the XCL206 PoL DCDC regulator. Unfortunately it is not a commonly stocked part. The ECP5 seems to run okay with a VCC of 1.2V, but I've been informed this can skew the duty cycle of clock-lines.

Closed 2020-11-01.

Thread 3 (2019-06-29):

Input Protection has invalid configuration

gregdavill, 2019-06-29:
The LTC4367 Circuit uses a voltage divider ladder to set OV/UV thresholds.

The numbering of these 3 resistors was reversed from calculation to schematic capture.

As a result the following permutation was performed: {R1,R2,R3} = {R3,R2,R1}

Closed 2020-11-01.

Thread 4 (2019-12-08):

Ethernet MDIO line needs pullup

gregdavill, 2019-12-08:
Add a 1K-4k7 pull-up to the MDIO line to the PHY.

Nightsd01, 2019-12-14:
Hey Greg, I am so impressed by this project but I have a quick question for you and couldn’t find a better place to ask. I’m a bit of a n00b with PCB design and I was wondering why some of the traces on your board seem to be so “squiggly” (for lack of a better word)?

Does it have something to do with avoiding signal interference? Or are you using it to make sure traces are of equal length even if they go to different places of the PCB?

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

gregdavill, 2019-12-15:
They're meandering traces. They are used to ensure signals transmitted from one chip arrive at the same time on the receiving chip.

Closed 2020-11-01.

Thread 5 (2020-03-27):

Hardware r0.3: Features/Suggestions

gregdavill, 2020-03-27:
I'm planing on refreshing this design based on experience with the current version.

These are the main features I'd personally like to cover:

- 2 Standard SYZYGY ports (each with: 32 I/O, 8 diff pairs, 2 dedicated clock pairs)
- 1 Transceiver SYZYGY port (all 4 SERDES lanes + ref clock)
- USBC + FX2/FTDI for debug/programming/HS USB interface
- RJ45 + GigE over RGMII, like the existing ButterStick
- Better VCCIO (possibly handled by the FX2)
- Replace HyperRAM with DDR3L (dual rank?)
- 5-8 Status LEDs FPGA controllable (RGB)
- more universial input power
- 2-3 Buttons
- Same Form Factor (80 x 49mm) _Keep the golden ratio!_

I'll entertain crowd-sourcing ideas because there are likely things I've not thought of. But understand that I'm clearly not able to include 100% of the ideas proposed. I'd still like to make this a general purpose development board, that can appeal to reasonably wide audience.

As with the previous designs the KiCad source files will be open-source so that anyone can study/remix this design if it doesn't quite fit their needs.

So, what else would you like to see on this board? :)

tommythorn, 2020-03-27:
You had me at DDR3L, especially if this would enable two 8Gib parts.  I presume that ~HDMI~ GPDI could be done over Transceiver SYZYGY?  Otherwise it would be useful to have a plan for digital video.

gregdavill, 2020-03-27:
Yes. Infact you could output over GPIO pins on any of the SYZYGY ports, upto 1080p30.
I'd like to experiment with the GPDI output at higher bitrates using the serdes, I think that should work, maybe even get to 4K? ;)

I'm not sure that I'd have enough extra pins/space to include a video out port on the board itself.

oskirby, 2020-03-27:
I think there's a lot of cool stuff you could do with the USB-C connector. It has high-speed lines that can be configured either as USB-SS, but also for HDMI or DisplayPort if you needed a video output port, though they will need a SERDES or two to use effectively.

USBC and power delivery also work well for your input power.

ewenmcneill, 2020-03-27:
Of possible relevance, there's been interest from, eg, some Debian developers in having a FPGA board with open source tools (eg, ECP5) which can run a soft CPU *and* have a decent amount of RAM connected to it to (a) be able to run Linux on the soft CPU, and (b) self host building a substantial portion of the (eg, Debian) Linux distribution  (One rapidly needs to be able to build Java, Python, Perl, Haskell, etc, to be able to build some of the fairly core libraries, like embedded databases, with all their language integrations, so the "base" RAM requirements for building a Linux distro are non-trivial.)  The idea is to have something that is open/inspectable from the bitstream up with no "closed" blobs.

The [TrellisBoard](https://github.com/daveshah1/TrellisBoard) 1GB (8 Gigabits) was heading in the right direction for them, but still too tight for building some of the larger language toolchains.  Having a way to get to 4x-8x that (so 4-8GB, ie 32-64 Gigabits), might make it quite useful to them, but even 2x (so 2GB, ie 16 Gigabits) could help.  That's possibly more than you'd want to/could put on an 80x49mm board.  But maybe there's a way to allow adding more via expansion ports?  (Ie, like the HyperRAM PMODs, but for larger RAM modules.)

Ewen

gregdavill, 2020-03-27:
@oskirby Thanks for the suggestions, the ECP5 only provides 4 serdes lanes in the package I'm looking at. I'd want all of these to go to the SZYZGY high-speed connector. Adding high-speed muxes is an option, but adds complications + costs. I do want to try experimenting with USBC USB3 / Alt modes on this. So I'll be creating some SZYZGY pods that connect the serdes parts up to a USBC connector.

@ewenmcneill Interesting thanks for this insight. Like the OrangeCrab the plan is to enable the hardware to support upto 8Gbit DDR3L chips (Although they're not great on the dollars/bits curve, compared with 1/2/4Gbit parts).
Due to the I/O constraints imposed by the ECP5 on DDR3 interfaces and each port only having 32 I/O pins, it may be tricky to add extra memory via a SZYZGY port.
An interesting idea might be to pair up 2 boards, and have an external bridge between them that can pull the extra memory from the second board into the address space of the first board with a linux capable soft processor.

ewenmcneill, 2020-03-28:
> An interesting idea might be to pair up 2 boards, and have an external bridge between them that can pull the extra memory from the second board into the address space of the first board with a linux capable soft processor.

@gregdavill That might be a really good way to approach it, especially if more than 2 boards could be daisy chained somehow and maybe multiple soft CPUs could be run on the set of boards.  That'd effectively give you SMP (Symmetric Multi-Processing) with each board having local CPU cores and local RAM, but also having a bus method to be able to access "far RAM" that's connected to another board.   (AMD used that kind of architecture for some of their CPU generations a few years ago IIRC, and the Linux kernel has built in support to try to optimise memory layout nearer the CPU core running the code to keep "far RAM" accesses less frequent.)

Ewen

mithro, 2020-03-28:
Let me leave this here --> https://github.com/enjoy-digital/liteiclink

mithro, 2020-03-28:
FYI -- @antmicro (like @kgugala) and @SpinalHDL are also working on bringing up SMP support in LiteX and VexRISCV.

mithro, 2020-03-28:
What you are talking about is called NUMA in x86 -- https://en.wikipedia.org/wiki/Non-uniform_memory_access

ewenmcneill, 2020-03-29:
> What you are talking about is called NUMA in x86 [...]
>  https://github.com/enjoy-digital/liteiclink

@mithro Thanks for the reminder of the  NUMA term; that what was I was trying to think of when describing a "two board" SMP (which actually wouldn't be symmetric if they have distinct local RAM).  And yes, Enjoy Digital's link-via-PCIe-connector idea, that you link to, was the sort of thing I had in mind for a board interconnect.

@gregdavill, possibly relevant to your design would be how easily a ECP5 5G part could be an option to place on the PCB, with the 5G enhanced pins facing, eg, one of the SYZYGY interfaces.  (I'm not sure off the top of my head how pin compatible the various ECP5 variants are, but it's at least worth considering if it's possible to arrange for the 5G enhanced pins to be used for a higher speed board to board interconnect for multi-board NUMA as a build option.)

Ewen

gregdavill, 2020-03-29:
A design goal will be to support the 5G parts.

One of the SYZYGY ports is a TXR-4 Transceiver type, which can support 4 TX/RX lanes. This is exactly how many lanes we have on the 381 package ECP5, and should enable some fun experiments. (SDI, display port, high res HDMI?, PCIe, SGMII, etc)

mithro, 2020-03-30:
@gregdavill - Would you be able to do a SYZYGY to [TOFE adapter board](https://tofe.io)? It should be also usable for SYZYGY to PCIe...

thejpster, 2020-12-18:
The 8P8C Ethernet Jack looks like it would get in the way of putting this module down onto a larger board (as you might fit a Raspberry Pi CM4 on to the Raspberry Pi IO board). Is it possible to get the Ethernet jack on the other side, or as a no-fit?

gregdavill, 2020-12-19:
@thejpster moving the Ethernet connector is not an option at this stage as the design work for this version has been completed now.

The board as designed is more configured to operate like a RPI+Hat rather than a CM4+base plate.

Closed 2021-01-10.

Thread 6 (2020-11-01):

RGMII straps

gregdavill, 2020-11-01:
Current schematic lists all the strap resistors for the RGMII as DNP.

This shouldn't cause any errors that can't be fixed in firmware.
But does mean that more settings are required to set via the MDIO interface.
Also the schematic/renderings show these resistors as present.

## Fix ##
 - R8: DNP -> 1K5
 - R9: DNP -> 1K5
 - R12: DNP -> 1K5
 - R13: DNP -> 1K5
 - R14: DNP -> 1K5
 - R15: DNP -> 1K5
 - R16: DNP -> 1K5
 - R17: DNP -> 1K5
 - R22: DNP -> 1K5
 - R23: DNP -> 1K5

Closed 2020-11-01.

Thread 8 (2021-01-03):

usb0.reset not present on 25F

gregdavill, 2021-01-03:
## Description

The ECP5 is available in 3 different densities: 25,45,85. While for the most part you can mix and match these, the smaller devices do not contain some I/O pins that are present on the larger devices.

On the ButterStick r1.0 prototypes
 - One of these pins has been allocated to handling `usb.reset`.
 - By default `usb0.reset` is pulled `LOW`

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

## Behavior

If a 25F device is fitted the USB PHY will never leave reset

---

## Proposed Fix

- Change R53 pull-down to pull-up
- Ensure gateware puts PHY into known good state with SW resets.

gregdavill, 2021-01-10:
Hardware has been modified with the proposed HW fix
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

Gateware has been tested with this fix in place
 - Removing `USB0.RESET` from gateware control (like it would be on the 25F part.
 - Gateware designed around Luna functioned correctly

Closed 2021-01-10.

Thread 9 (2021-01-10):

Inconsistent BOM parts for LFE5UM5G

gregdavill, 2021-01-10:
##Issue

BOM lists the main FPGA `U4` as `LFE5UM5G-85F-8BG381I`
This part requires 1v2 for the core and SERDES voltages.

However the BOM lists parts that would provide 1v1. The 1v2 is listed as an option on the schematic, not mentioned in the BOM.

## Proposed fix

 - Make 1v2 the default option to match `U4`.
 - Update schematic to show 1v1 options

This requires the following steps:
 - Update Value of `R74` to 118k
 - Update Value of `R60` to 118k
 - Update Value of `R65` to 100k
 - Rename `P_1V1_A` to `P_1V2_A`
 - Rename `P_1V1_T` to `P_1V2_A`
 - Rename `+1v1` to `P_FPGA_1V2`
 - Regenerate BOM/Schematics

Closed 2021-01-10.

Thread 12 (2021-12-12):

LED G & B control signals are crossed.

TomKeddie, 2021-12-12:
In this schematic excerpt you can see LEDG is driving CATB and LEDB is driving CATG.  Is easily fixed in the platform definitions but the schematic labels could be updated to swap LEDG and LEDB for clarity.

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

nandland, 2022-06-06:
I found this issue as well... scratching my head wondering why the Blue LED is turning on when I specifically asked for green. :)

gregdavill, 2022-06-07:
Thanks for picking this up Tom.

The easiest fix is to swap the signals from the FPGA to this page. Q2/Q3 will still control Blue/Green respectively. But now the signals are correctly named from the FPGA.

Closed 2022-06-07.

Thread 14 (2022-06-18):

Programming over USB timeouts

holstvoogd, 2022-06-18:
Hi,

I just received my Butterstick 1.0a yesterday & have been having trouble programming it. Basically the DFU download fails at a random percentage. So far I've only been succesful once or twice in putting a new bitstream on the device.

I've tried on different machines (albeit all ARM machines, m1 mac & a RPI) & with multiple different usb cables.

I've build a basic SoC with Litex, based on the litex-example and the litex-boards project, and use dfu-util to download the bitstream to the board. The debug output for a random build:

```
dfu-util --alt 0 --reset --download build/gsd_butterstick/gateware/gsd_butterstick.bit.dfu -vvv
dfu-util 0.11

Copyright 2005-2009 Weston Schmidt, Harald Welte and OpenMoko Inc.
Copyright 2010-2021 Tormod Volden and Stefan Schmidt
This program is Free Software and has ABSOLUTELY NO WARRANTY
Please report bugs to http://sourceforge.net/p/dfu-util/tickets/

libusb version 1.0.26 (11724)
DFU suffix version 100
Match vendor ID from file: 1209
Match product ID from file: 5af1
[timestamp] [threadID] facility level [function call] <message>
--------------------------------------------------------------------------------
[ 0.004686] [002648ea] libusb: debug [libusb_get_device_list]
[ 0.004706] [002648ea] libusb: debug [libusb_get_device_descriptor]
[ 0.004708] [002648ea] libusb: debug [libusb_get_config_descriptor] index 0
[ 0.004712] [002648ea] libusb: debug [libusb_open] open 0.1
[ 0.004769] [002648ea] libusb: debug [darwin_open] device open for access
[ 0.004773] [002648ea] libusb: debug [libusb_submit_transfer] transfer 0x14e004350
[ 0.004811] [002648ea] libusb: debug [libusb_get_next_timeout] no URB with timeout or all handled by OS; no timeout!
[ 0.004815] [002648ea] libusb: debug [libusb_handle_events_timeout_completed] doing our own event handling
[ 0.004817] [002648ea] libusb: debug [handle_events] event sources modified, reallocating event data
[ 0.004821] [002648ea] libusb: debug [usbi_wait_for_events] poll() 1 fds with timeout in 60000ms
[ 0.005111] [002648ed] libusb: debug [darwin_async_io_callback] an async io operation has completed
[ 0.005130] [002648ea] libusb: debug [usbi_wait_for_events] poll() returned 1
[ 0.005133] [002648ea] libusb: debug [handle_event_trigger] event triggered
[ 0.005134] [002648ea] libusb: debug [darwin_handle_transfer_completion] handling transfer completion type control with kernel status 0
[ 0.005137] [002648ea] libusb: debug [usbi_handle_transfer_completion] transfer 0x14e004350 has callback 0x1045b8994
[ 0.005139] [002648ea] libusb: debug [sync_transfer_cb] actual_length=4
[ 0.005141] [002648ea] libusb: debug [libusb_free_transfer] transfer 0x14e004350
[ 0.005144] [002648ea] libusb: debug [libusb_submit_transfer] transfer 0x14ce04540
[ 0.005169] [002648ea] libusb: debug [libusb_get_next_timeout] no URB with timeout or all handled by OS; no timeout!
[ 0.005172] [002648ea] libusb: debug [libusb_handle_events_timeout_completed] doing our own event handling
[ 0.005174] [002648ea] libusb: debug [usbi_wait_for_events] poll() 1 fds with timeout in 60000ms
[ 0.005180] [002648ed] libusb: debug [darwin_async_io_callback] an async io operation has completed
[ 0.005186] [002648ea] libusb: debug [usbi_wait_for_events] poll() returned 1
[ 0.005187] [002648ea] libusb: debug [handle_event_trigger] event triggered
[ 0.005189] [002648ea] libusb: debug [darwin_handle_transfer_completion] handling transfer completion type control with kernel status 0
[ 0.005190] [002648ea] libusb: debug [usbi_handle_transfer_completion] transfer 0x14ce04540 has callback 0x1045b8994
[ 0.005192] [002648ea] libusb: debug [sync_transfer_cb] actual_length=54
[ 0.005194] [002648ea] libusb: debug [libusb_free_transfer] transfer 0x14ce04540
[ 0.005197] [002648ea] libusb: debug [libusb_submit_transfer] transfer 0x14ce04540
[ 0.005224] [002648ea] libusb: debug [libusb_get_next_timeout] no URB with timeout or all handled by OS; no timeout!
[ 0.005227] [002648ea] libusb: debug [libusb_handle_events_timeout_completed] doing our own event handling
[ 0.005228] [002648ea] libusb: debug [usbi_wait_for_events] poll() 1 fds with timeout in 60000ms
[ 0.005616] [002648ed] libusb: debug [darwin_async_io_callback] an async io operation has completed
[ 0.005631] [002648ea] libusb: debug [usbi_wait_for_events] poll() returned 1
[ 0.005635] [002648ea] libusb: debug [handle_event_trigger] event triggered
[ 0.005636] [002648ea] libusb: debug [darwin_handle_transfer_completion] handling transfer completion type control with kernel status 0
[ 0.005638] [002648ea] libusb: debug [usbi_handle_transfer_completion] transfer 0x14ce04540 has callback 0x1045b8994
[ 0.005640] [002648ea] libusb: debug [sync_transfer_cb] actual_length=4
[ 0.005642] [002648ea] libusb: debug [libusb_free_transfer] transfer 0x14ce04540
[ 0.005645] [002648ea] libusb: debug [libusb_submit_transfer] transfer 0x14e004350
[ 0.005661] [002648ea] libusb: debug [libusb_get_next_timeout] no URB with timeout or all handled by OS; no timeout!
[ 0.005663] [002648ea] libusb: debug [libusb_handle_events_timeout_completed] doing our own event handling
[ 0.005665] [002648ea] libusb: debug [usbi_wait_for_events] poll() 1 fds with timeout in 60000ms
[ 0.005672] [002648ed] libusb: debug [darwin_async_io_callback] an async io operation has completed
[ 0.005686] [002648ea] libusb: debug [usbi_wait_for_events] poll() returned 1
[ 0.005689] [002648ea] libusb: debug [handle_event_trigger] event triggered
[ 0.005690] [002648ea] libusb: debug [darwin_handle_transfer_completion] handling transfer completion type control with kernel status 0
[ 0.005692] [002648ea] libusb: debug [usbi_handle_transfer_completion] transfer 0x14e004350 has callback 0x1045b8994
[ 0.005694] [002648ea] libusb: debug [sync_transfer_cb] actual_length=40
[ 0.005697] [002648ea] libusb: debug [libusb_free_transfer] transfer 0x14e004350
[ 0.005700] [002648ea] libusb: debug [libusb_close]
[ 0.005731] [002648ea] libusb: debug [libusb_get_device_descriptor]
[ 0.005735] [002648ea] libusb: debug [libusb_get_config_descriptor] index 0
[ 0.005743] [002648ea] libusb: debug [libusb_get_device_descriptor]
[ 0.005745] [002648ea] libusb: debug [libusb_get_config_descriptor] index 0
[ 0.005747] [002648ea] libusb: debug [libusb_get_device_descriptor]
[ 0.005748] [002648ea] libusb: debug [libusb_get_config_descriptor] index 0
[ 0.005751] [002648ea] libusb: debug [libusb_get_device_descriptor]
[ 0.005752] [002648ea] libusb: debug [libusb_get_config_descriptor] index 0
[ 0.005753] [002648ea] libusb: debug [parse_endpoint] skipping descriptor 0x30
Opening DFU capable USB device...
[ 0.005758] [002648ea] libusb: debug [libusb_open] open 0.1
[ 0.005800] [002648ea] libusb: debug [darwin_open] device open for access
Device ID 1209:5af1
Device DFU version 0101
DFU attributes: (0x0d) bitCanDnload bitManifestationTolerant bitWillDetach
Detach timeout 50 ms
Claiming USB DFU Interface...
[ 0.005814] [002648ea] libusb: debug [libusb_claim_interface] interface 0
[ 0.006195] [002648ea] libusb: debug [get_endpoints] building table of endpoints.
[ 0.006216] [002648ea] libusb: debug [darwin_claim_interface] interface opened
Setting Alternate Interface #0 ...
[ 0.006220] [002648ea] libusb: debug [libusb_set_interface_alt_setting] interface 0 altsetting 0
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
luigifcruz, 2022-09-12:
Awesome, @gregdavill! Thanks for the update. I'll try to flash the new bootloader to the board tonight. I have a Tigard so no problem if it gets bricked.

gregdavill, 2022-09-12:
Sure. I'll wait until you've tested it. Then I'll merge it into a v1.4 release.

The changes are quite simple, it was just knowing where to look https://github.com/butterstick-fpga/butterstick-bootloader/compare/fix/out-enable-bug

luigifcruz, 2022-09-13:
I just tested the experimental bootloader binary, @gregdavill. I flashed it using Tigard and verified the version with `lsusb`.
```
Bus 002 Device 008: ID 1209:5af1 1209 butterstick (dfu 7058dc2)  Serial: e460-5107-a338-4d21
```
Then, I tested flashing a sample project in DFU mode using the `dfu-util` command below.
```
dfu-util -v --alt 0 --download build/gsd_butterstick/gateware/gsd_butterstick.bit --reset
```
Perhaps a little bit slower than the previous version, but the flashing itself works. But when `dfu-utils` tries to reset the board, it throws a timeout for some reason. The command without the `--reset` works just fine but the board isn't reset. I copied and pasted the output below.
```
def-util 0.11

libusb version 1.0.26 (11724)
dfu-util: Warning: Invalid DFU suffix signature
dfu-util: A valid DFU suffix will be required in a future dfu-util release
Opening DFU capable USB device...
Device ID 1209:5af1
Device DFU version 0101
DFU attributes: (0x0d) bitCanDnload bitManifestationTolerant bitWillDetach
Detach timeout 50 ms
Claiming USB DFU Interface...
Setting Alternate Interface #0 ...
Determining device status...
DFU state(2) = dfuIDLE, status(0) = No error condition is present
DFU mode device DFU version 0101
Device returned transfer size 512
Copying data from PC to DFU device
Download        [=========================] 100%      2029720 bytes
Download done.
Sent a total of 2029720 bytes
DFU state(7) = dfuMANIFEST, status(0) = No error condition is present
DFU state(2) = dfuIDLE, status(0) = No error condition is present
Done!
Resetting USB to switch back to Run-Time mode
dfu-util: error resetting after download: LIBUSB_ERROR_TIMEOUT
```

luigifcruz, 2022-09-13:
Sidenote: I tried to debug the reset error on a VM. It worked the first time, but the second time it got stuck just like macOS. The funny thing was that instead of throwing a timeout message, the whole VM crashed. 😅

gregdavill, 2022-09-13:
Hmm, that's a bit strange.
But it might be a combination of 2 settings, clashing.

First, we have `bitWillDetach` set. Per the DFU SPec:
```
Device will perform a bus detach-attach sequence when it receives a DFU_DETACH request.
The host must not issue a USB Reset. (bitWillDetach)
0 = no
1 = yes
```

And `wDetachTimeOut` being set to 50ms.
```
Time, in milliseconds, that the device will wait after receipt of the DFU_DETACH request. If this time
elapses without a USB reset, then the device will terminate the Reconfiguration phase and revert
back to normal operation. This represents the maximum time that the device can wait (depending on its
timers, etc.). The host may specify a shorter timeout in the DFU_DETACH request.
```

On a Detach request we actually wait 100ms, then cut the USB link before booting into the user app.
So a well behaved host, likely sends a `DFU_DETACH` command. Waits 50ms. We've not re-attached like we've indicated with `bitWillDetach` so dfu-util tried to perform a bus reset, and that times out because we're basically in the process of disconnecting from the host.

I'll adjust these settings, we should be able to fix that so that dfu-util exits cleanly. :)

gregdavill, 2022-09-14:
Actually looking a bit further into it, using the `-R` option in dfu-util always results in it attempting to reset the USB device, and ends up with a return code of -4. Because the device is not present.

If you do a `--download` then in a second command run `--detach` you don't get the same behaviour. :doh:
That's a different issue though.

gregdavill, 2022-09-21:
Updated bootloader published as v1.4 should fix the timeout issues, and also fix the errors when using, it should now return with a clean return code.
```
dfu-util -a 0 -D <file> -R
```

https://github.com/butterstick-fpga/butterstick-bootloader/releases/tag/v1.4

luigifcruz, 2022-09-21:
Awesome @gregdavill! I'm a bit busy this week but I will try to test it in the next week. Thanks!

gregdavill, 2023-02-08:
Thanks for testing @luigifcruz. @holstvoogd Do you have some spare cycles to try and see if this fixes the issue?

holstvoogd, 2023-02-22:
@gregdavill I'm afraid I've lost track of my butter stick at the moment 😅 When I find it, I'll give it a try!

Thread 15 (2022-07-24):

[docs] clockspeed incorrect?

holstvoogd, 2022-07-24:
All the documentation & production info at groupgets says it has a 60mhz clock.
However the schematics and example projects say 30mhz.

After some testing counting leds, I'm pretty sure it is _actually_ 30mhz, correct?

gregdavill, 2022-07-24:
Yes, it is a 30MHz oscillator, the internal PLL boosts this upto 60MHz for USB or 125MHz for Ethernet.

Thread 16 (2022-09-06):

Weird RGB behaviour.

luigifcruz, 2022-09-06:
I'm not sure if this is a hardware or software problem, but the RGB LEDs of my Butterstick appear to be behaving strangely. I tested all the `user_led_color` combinations below. It looks like only the RED LED can be ON at any given time. Is this intended or faulty hardware?

```
        # 000: N/A
        # 001: R
        # 010: B
        # 011: R
        # 100: G
        # 101: R
        # 110: G+B
        # 111: R
```

gregdavill, 2022-09-07:
This is expected with the current logic in LiteX. The circuitry for the LEDs is set up in a multiplexing manner. So the basic drive logic that is using `user_led_color` as an input only supports selecting one of R/G/B.

In order to get multiple colours the logic behind that would need to multiplex between the different colours, which it currently doesn't do, instead it simply uses the value passed to `user_led_color` to drive the mosfets shown below.

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

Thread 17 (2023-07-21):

Assembled PCBs link don't work

LaneaLucy, 2023-07-21:
When I open the link, I only get the homepage and when I search for butter stick on it, I only find the SYZYGY Breakout board for Butterstick

gregdavill, 2023-07-27:
I'll check but this probably means that the first batch of boards has entirely sold out.

LaneaLucy, 2023-07-28:
Is there any other option to get a preassembled one, maybe even with other ram chips? Found the MT41K512M16VRP-107 which should be pin compatible, except that one pin, that is NC is a extra address pin, but the schematic show, that this pin is already connected. And I would really like to get one with even more ram

gregdavill, 2023-08-26:
Closing because the link on the main page now works again. (while stock is available)

I'm able to do rework for different RAM alterations. Just drop me an email, it's listed on my profile :+1:

Closed 2023-08-26.

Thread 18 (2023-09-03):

VID seems... wrong?

Goof512, 2023-09-03:
Hi,

I'm working on getting the linux-on-litex-riscv project to build onto butterstick, and I noticed the ID from `lsusb` is showing up as "1209:5af1", whereas documentation seems to suggest it should be "0403:6014"

Is this a manufacturing revision that wasn't documented? or is this a *me* problem that I just didn't realize I'd walked into?
DFU upload using the tutorial doesn't show any errors, and flashes the board correctly, which confuses me deeply.

I'm kinda new to FPGA toolchains, so I'm not quite sure how to proceed.

Environment:

Mac x86 on Monterey 12.6
open-ocd v0.10.0 from xPack
yosys etc. from oss-cad-suite

Goof512, 2023-09-04:
After more research, it appears there is no option to use DFU to

gregdavill, 2023-09-04:
Do you have a link to any documentation that lists `0403:6014`? As that's the PID/VID pair for FTDI 2232H, not the DFU interface.

Goof512, 2023-09-04:
that was entirely the problem, yes. I closed this because it was a stupid mistake - I hadn't realized the OpenOCD configuration was designed against a separate programmer.

Closed 2023-09-04.

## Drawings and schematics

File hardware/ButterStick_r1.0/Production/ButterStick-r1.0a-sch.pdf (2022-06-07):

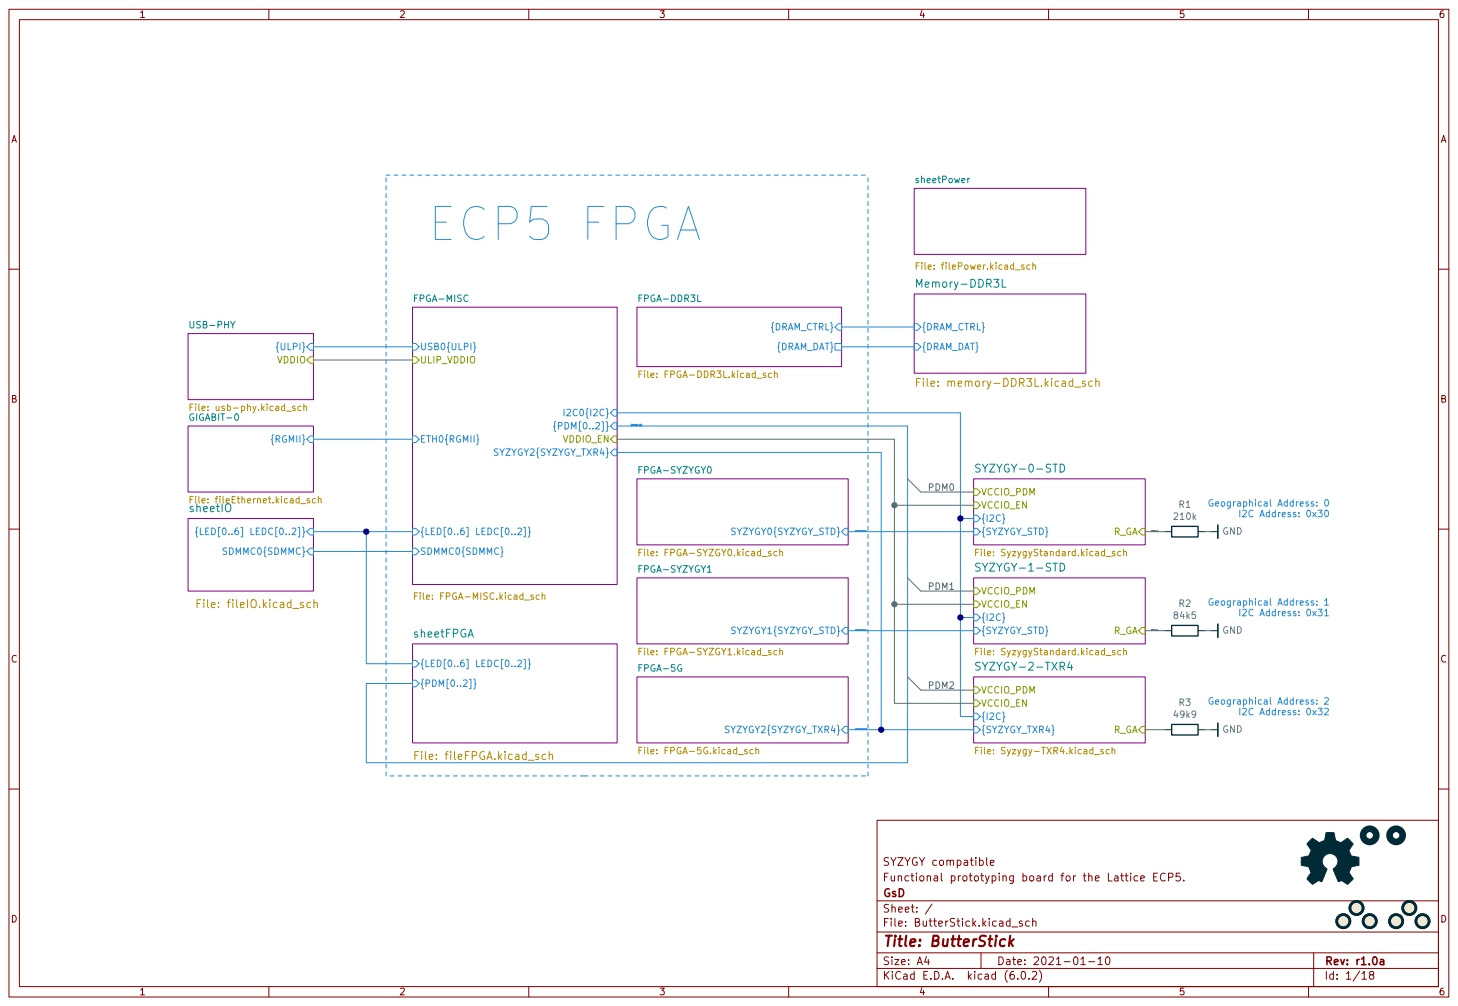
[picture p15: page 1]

File: usb-phy.kicad_sch
{RGMII} GIGABIT-0 File: fileEthernet.kicad_sch

SYZYGY compatible
Functional prototyping board for the Lattice ECP5.
File: ButterStick.kicad_sch Sheet: / GsD

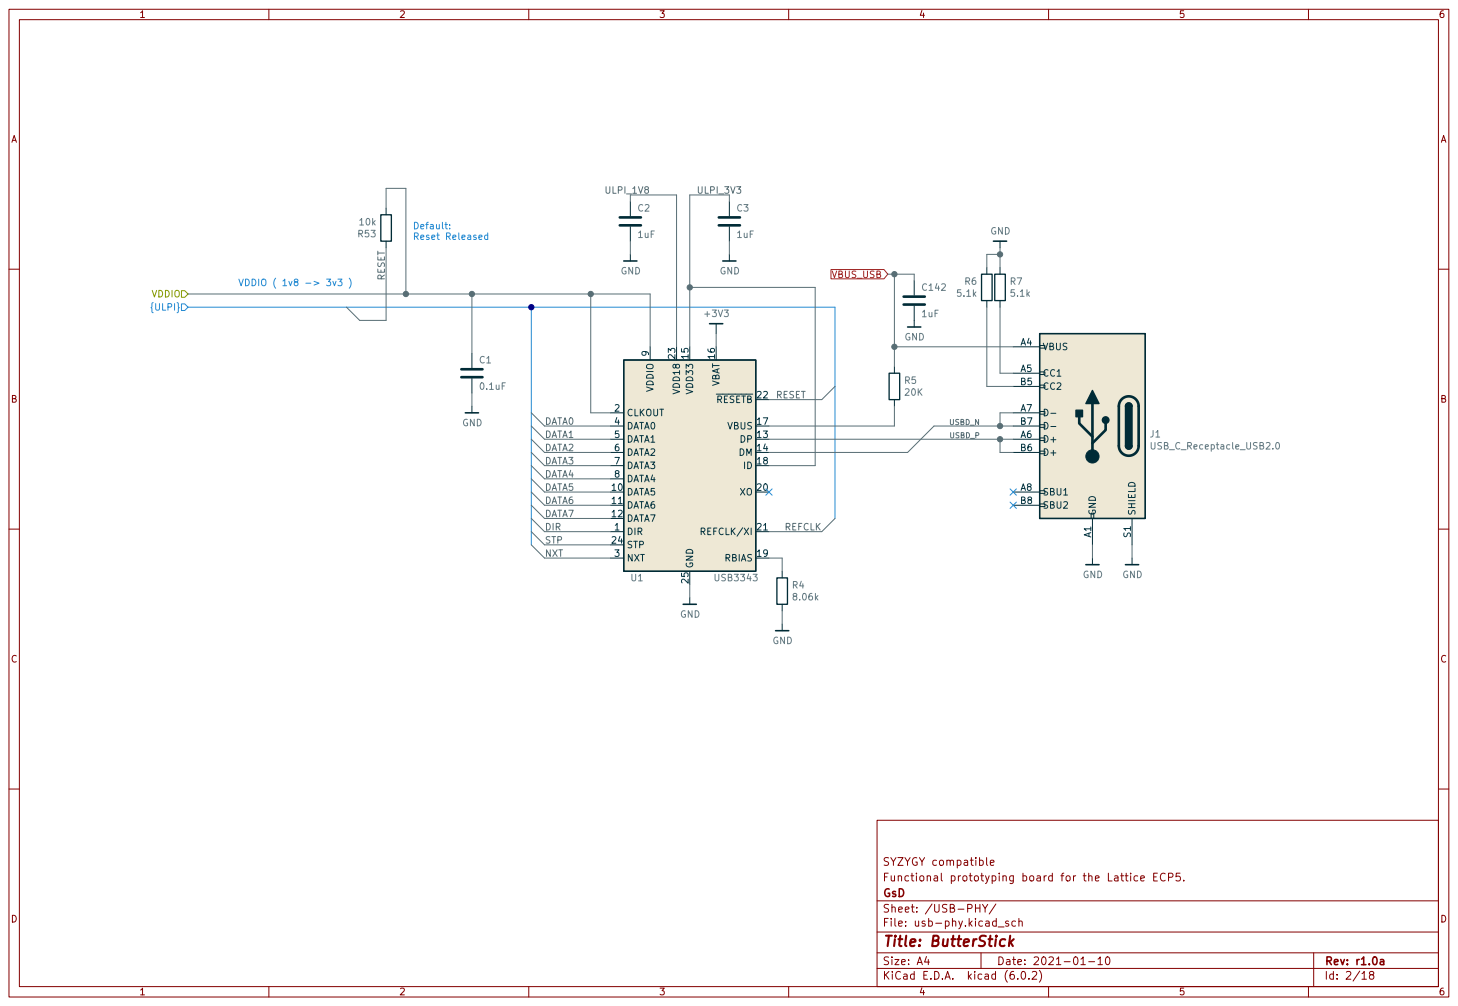
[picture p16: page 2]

SYZYGY compatible
Functional prototyping board for the Lattice ECP5.
File: usb-phy.kicad_sch Sheet: /USB-PHY/ GsD

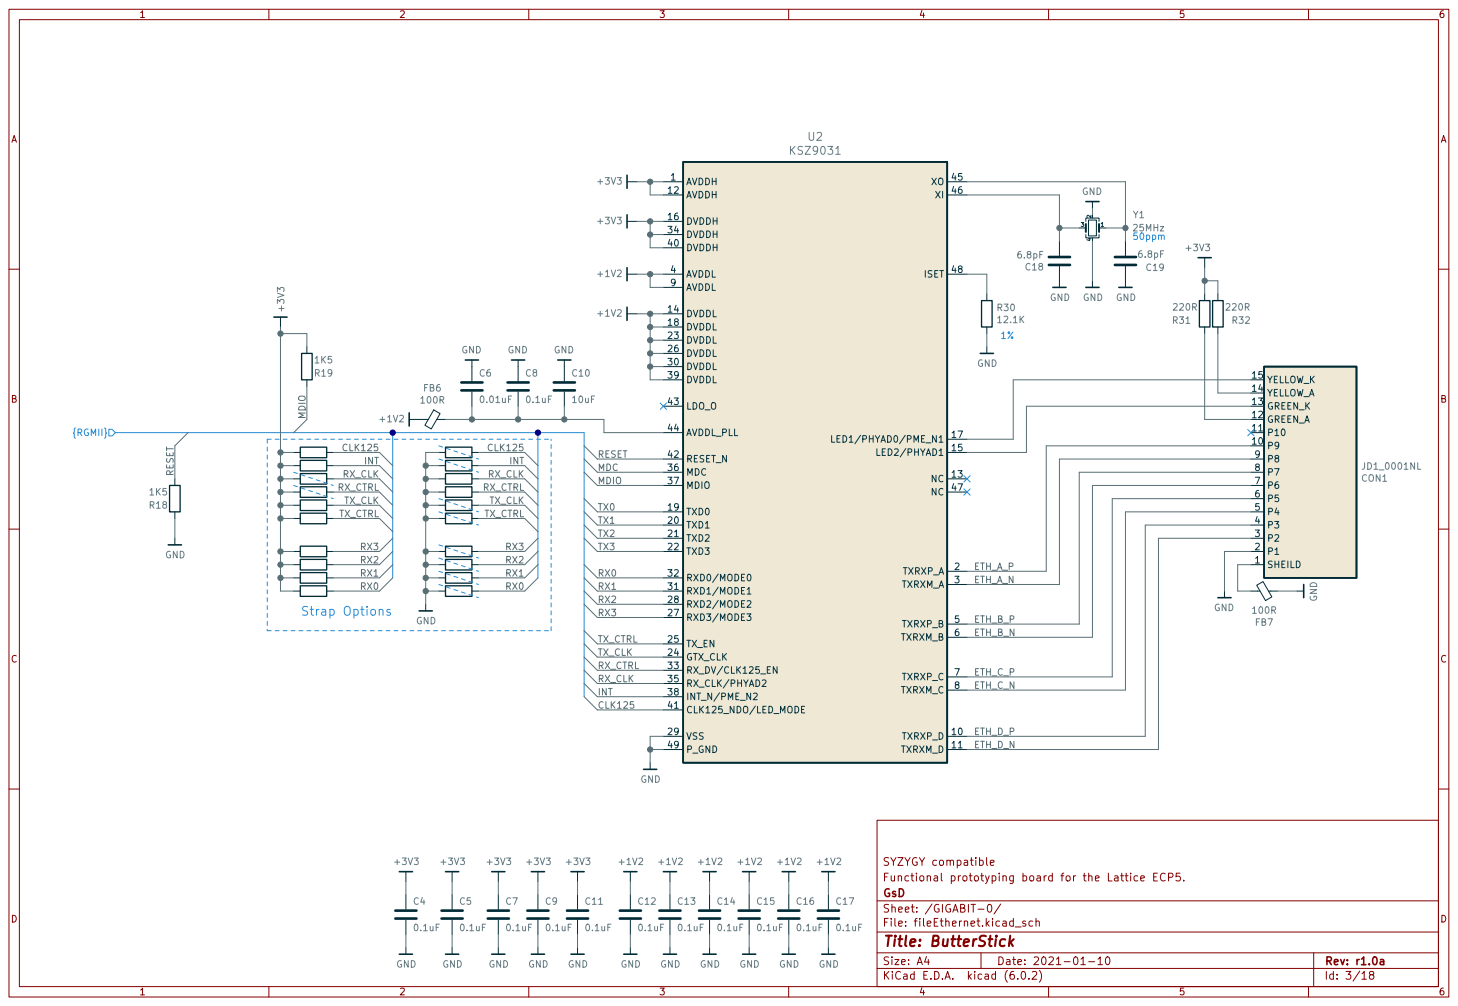
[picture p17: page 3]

SYZYGY compatible
Functional prototyping board for the Lattice ECP5.
File: fileEthernet.kicad_sch Sheet: /GIGABIT-0/ GsD

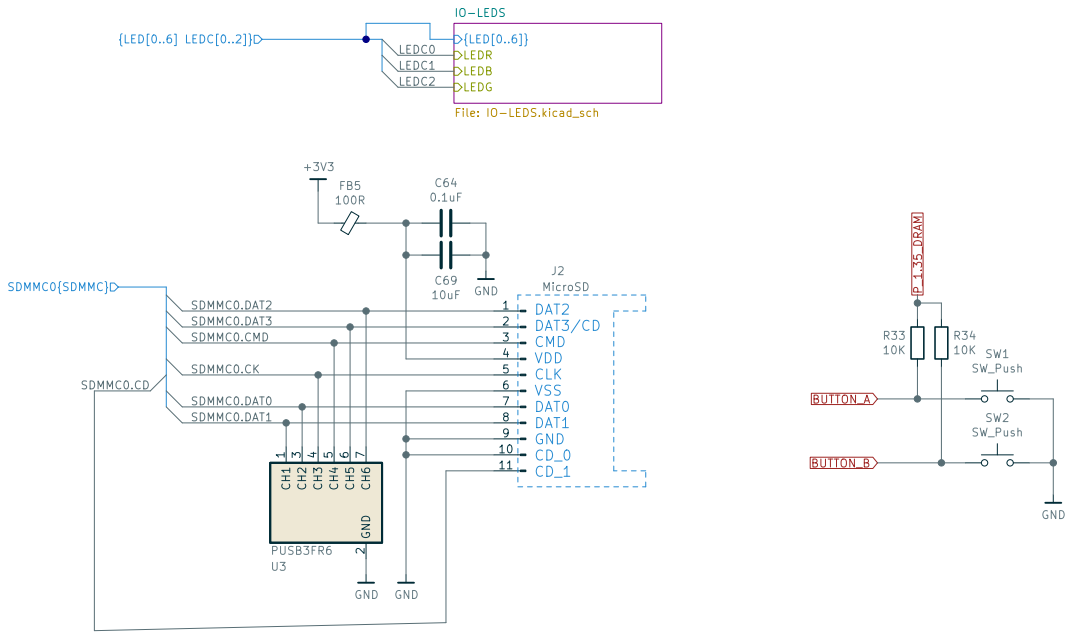
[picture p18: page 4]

SYZYGY compatible
Functional prototyping board for the Lattice ECP5.
File: fileIO.kicad_sch Sheet: /sheetIO/ GsD

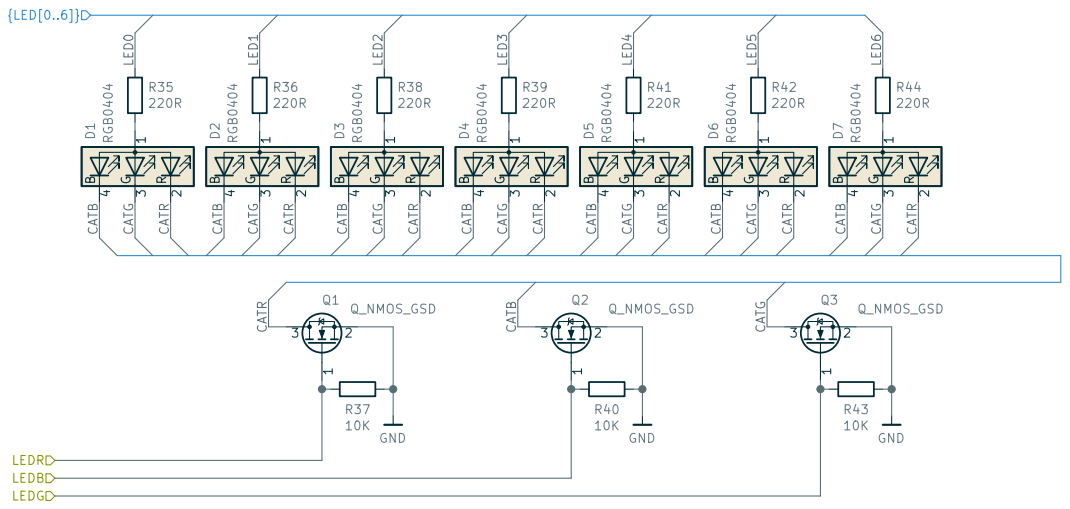
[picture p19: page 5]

SYZYGY compatible
Functional prototyping board for the Lattice ECP5.
File: IO-LEDS.kicad_sch Sheet: /sheetIO/IO-LEDS/ GsD

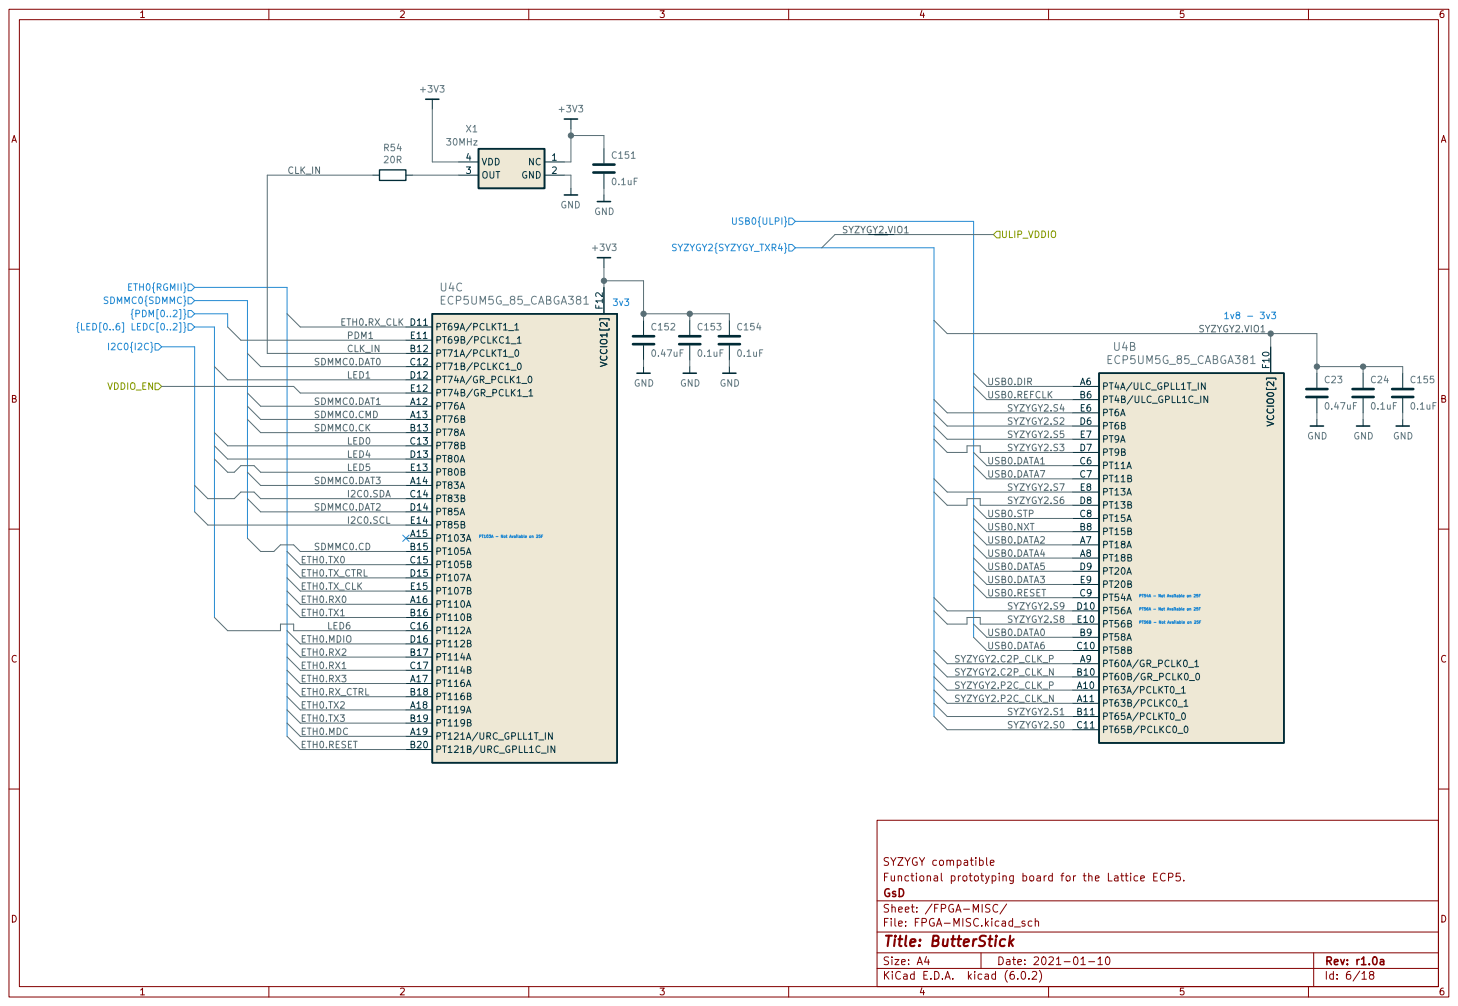
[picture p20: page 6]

PT54A - Not Available on 25F PT56A - Not Available on 25F 3v3

Functional prototyping board for the Lattice ECP5.
File: FPGA-MISC.kicad_sch Sheet: /FPGA-MISC/ GsD

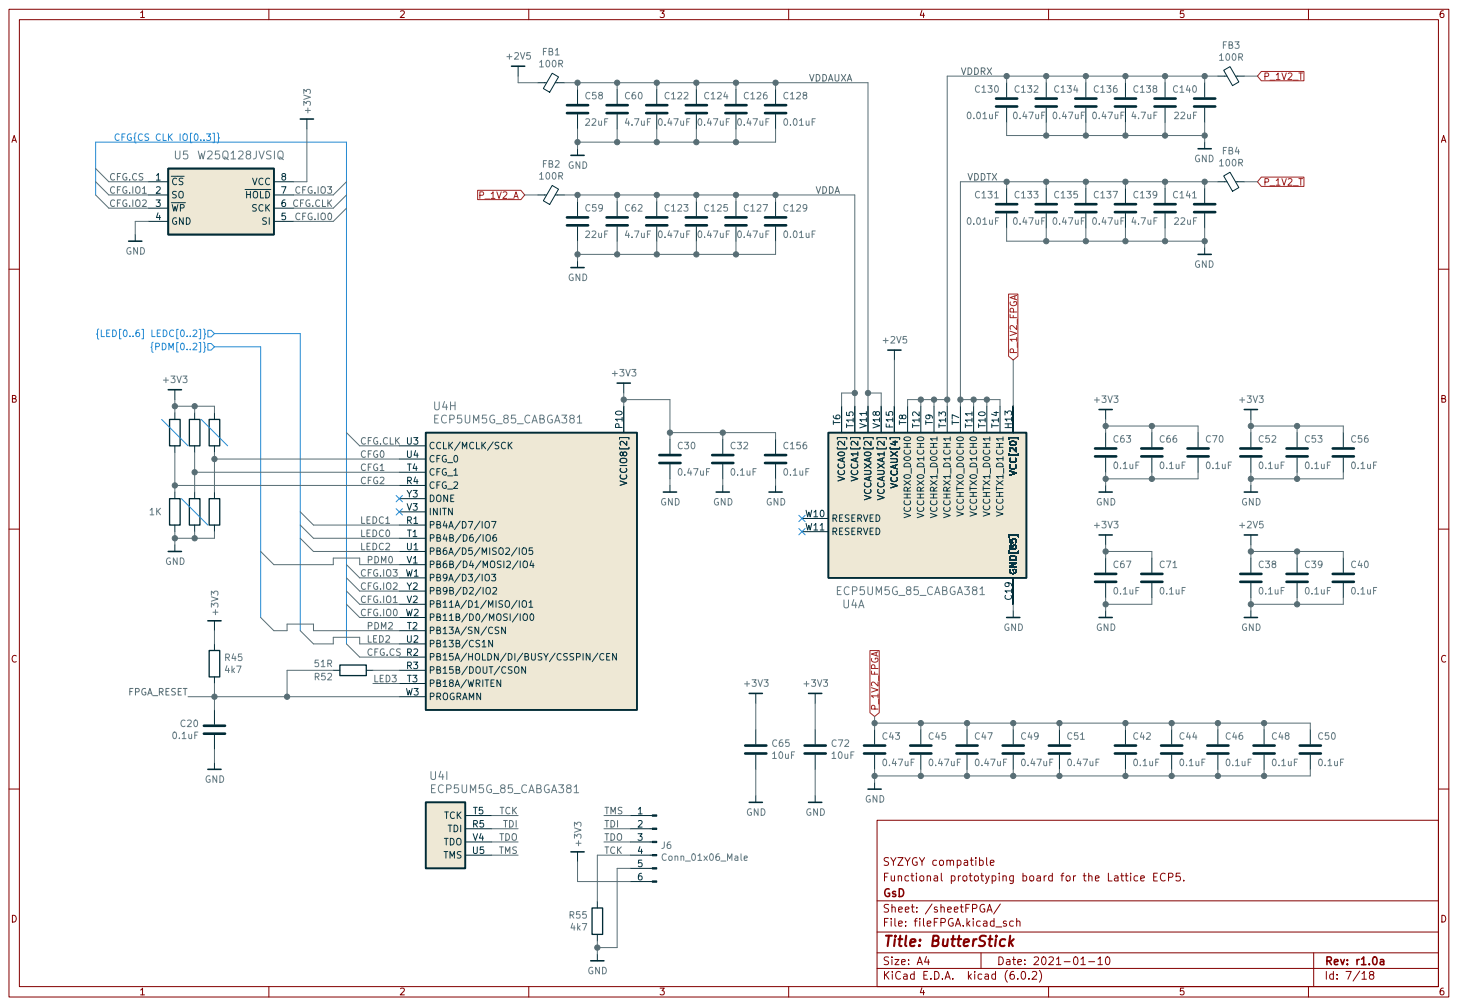
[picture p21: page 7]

SYZYGY compatible
Functional prototyping board for the Lattice ECP5.
File: fileFPGA.kicad_sch Sheet: /sheetFPGA/ GsD

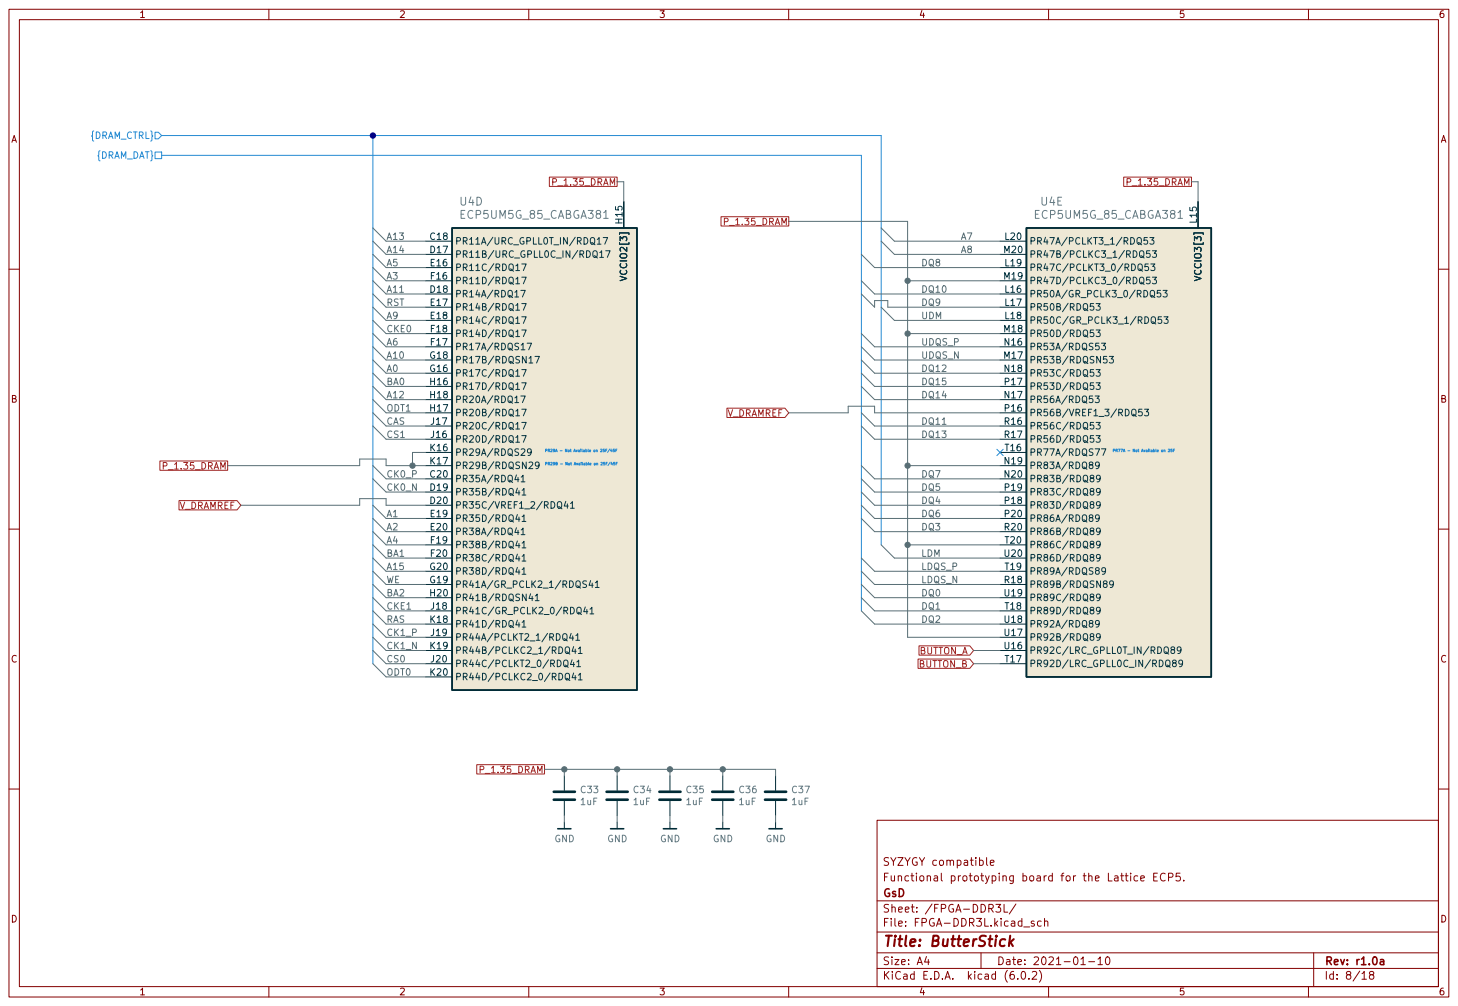
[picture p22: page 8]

Functional prototyping board for the Lattice ECP5.
File: FPGA-DDR3L.kicad_sch Sheet: /FPGA-DDR3L/ GsD

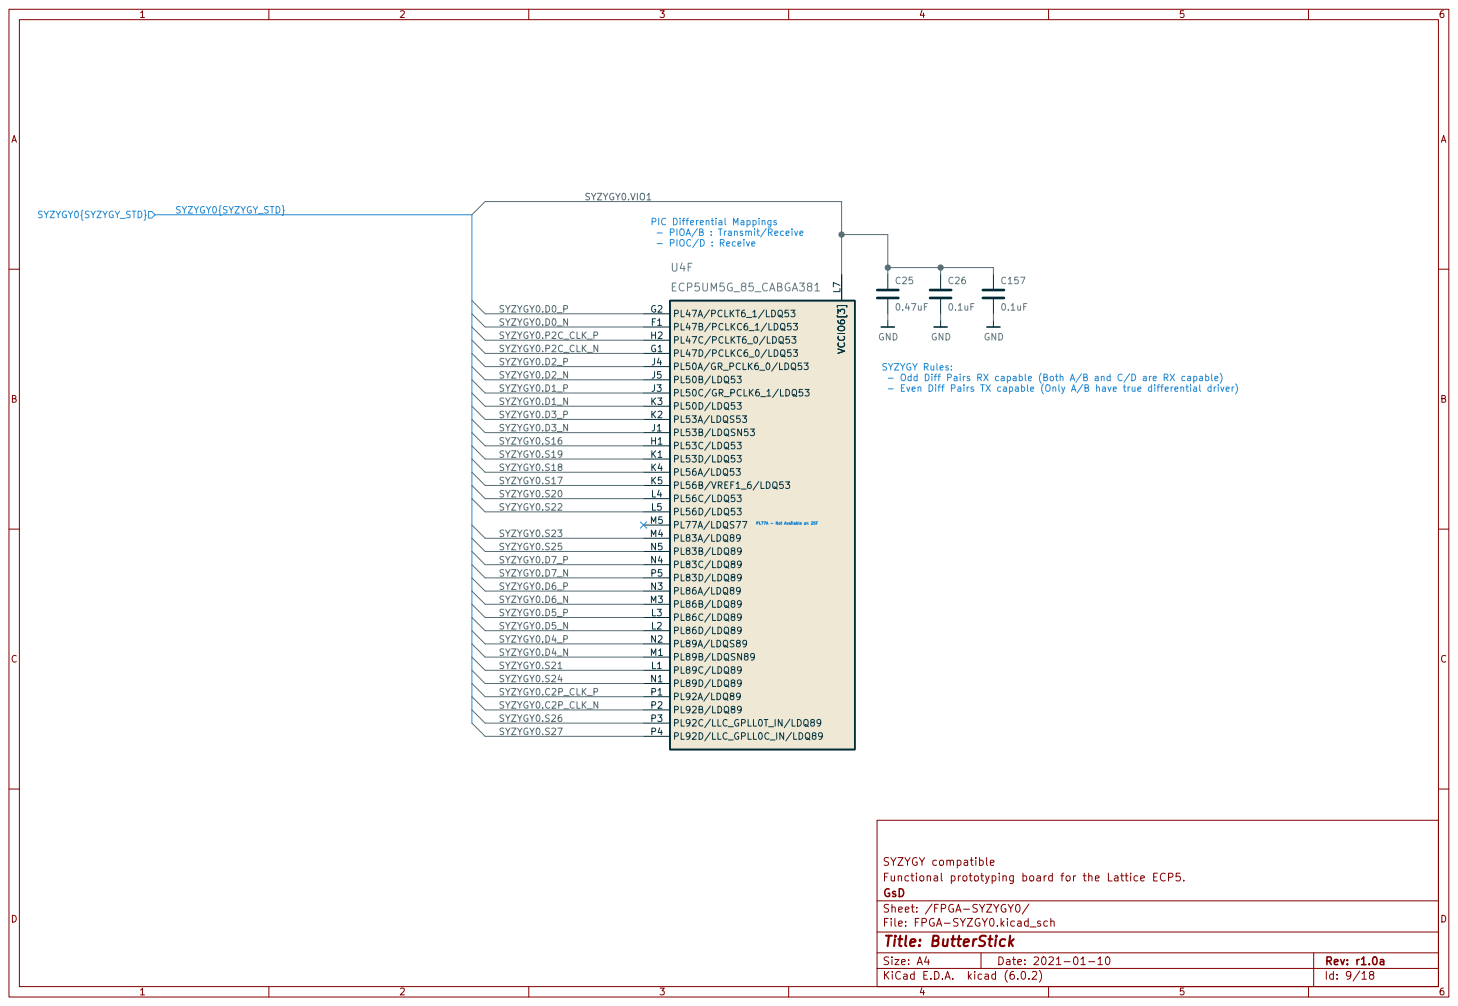
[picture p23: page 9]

- Odd Diff Pairs RX capable (Both A/B and C/D are RX capable)
- Even Diff Pairs TX capable (Only A/B have true differential driver)

SYZYGY compatible
Functional prototyping board for the Lattice ECP5.
File: FPGA-SYZGY0.kicad_sch Sheet: /FPGA-SYZYGY0/ GsD

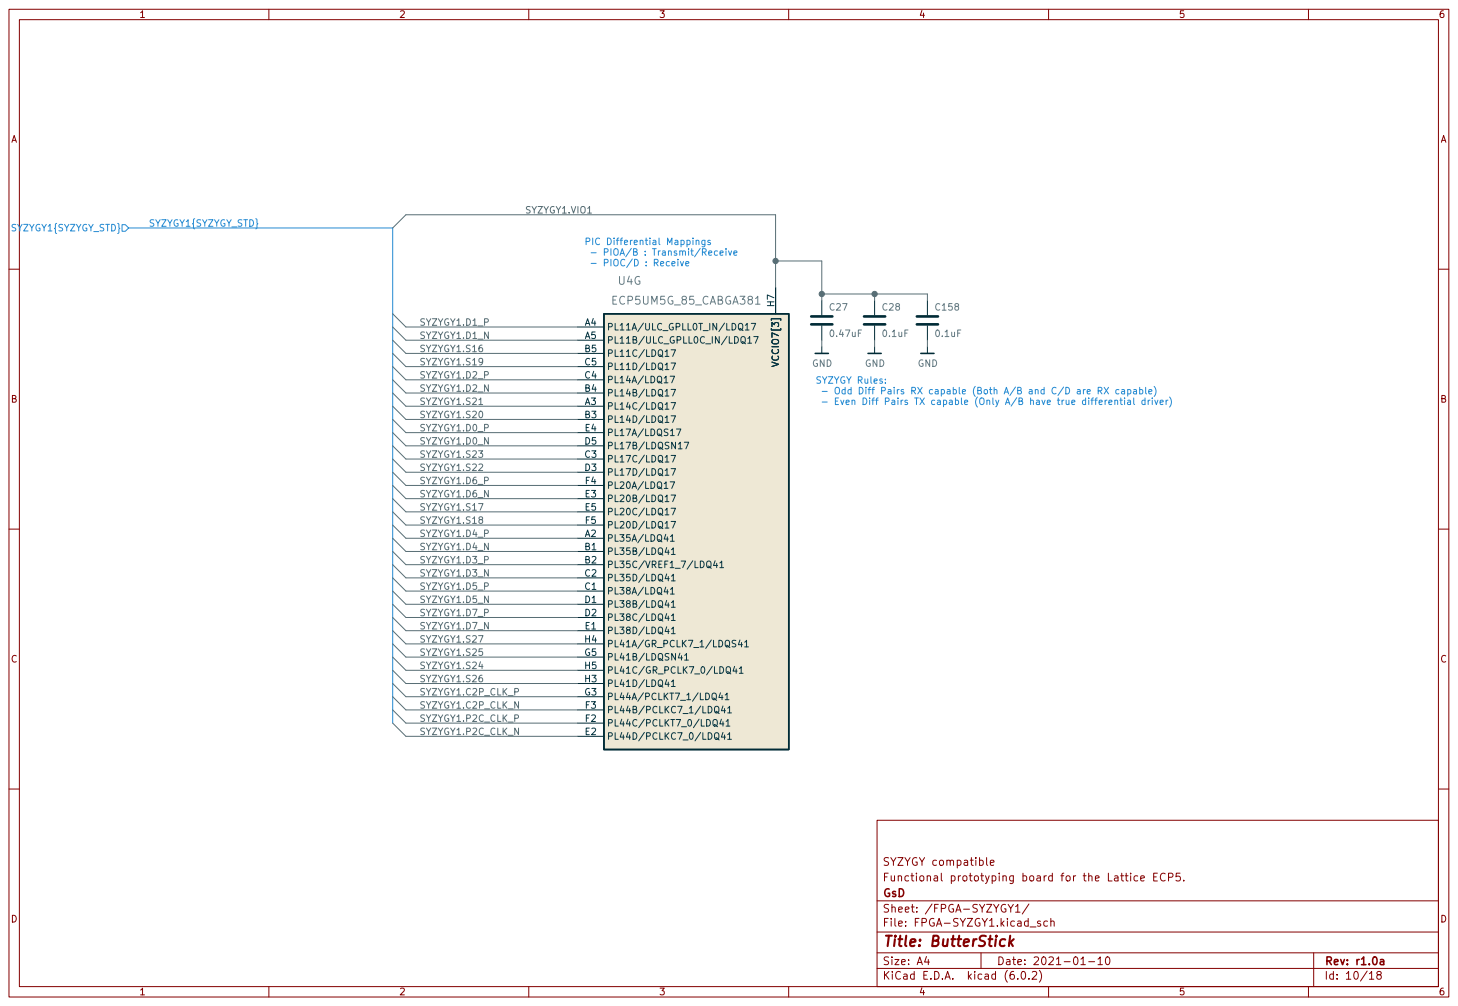
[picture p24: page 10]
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

Functional prototyping board for the Lattice ECP5.
File: FPGA-SYZGY1.kicad_sch Sheet: /FPGA-SYZYGY1/ GsD

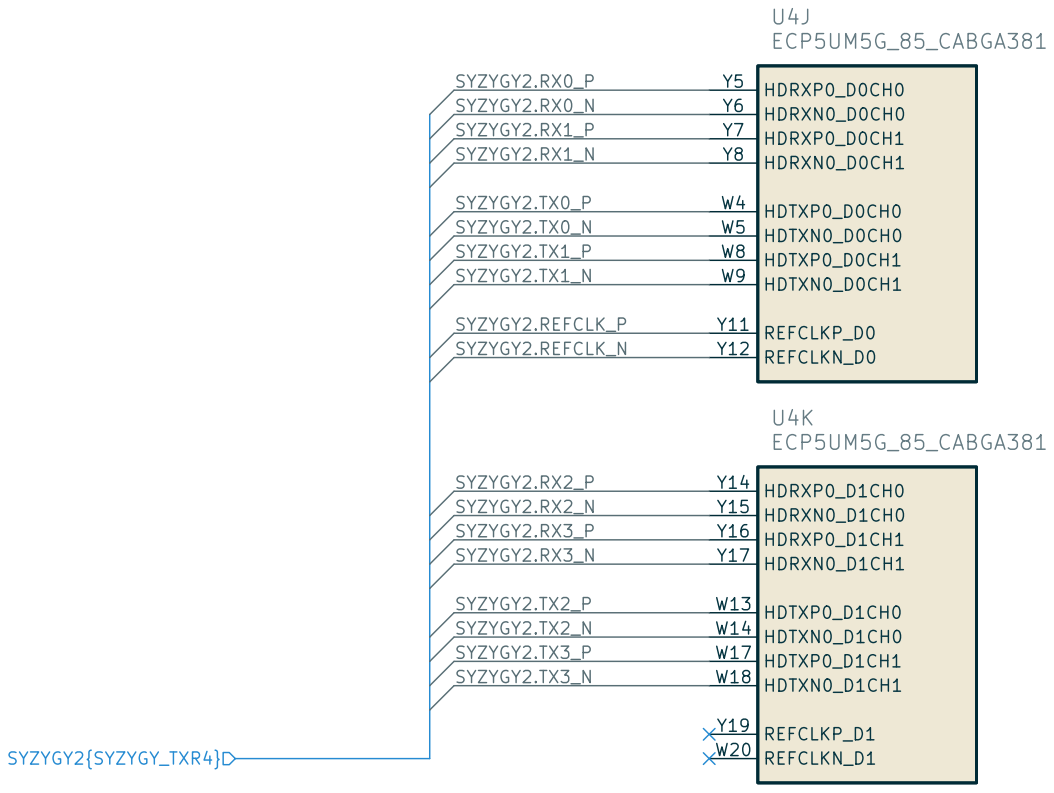
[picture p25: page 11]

Functional prototyping board for the Lattice ECP5.
File: FPGA-5G.kicad_sch Sheet: /FPGA-5G/ GsD

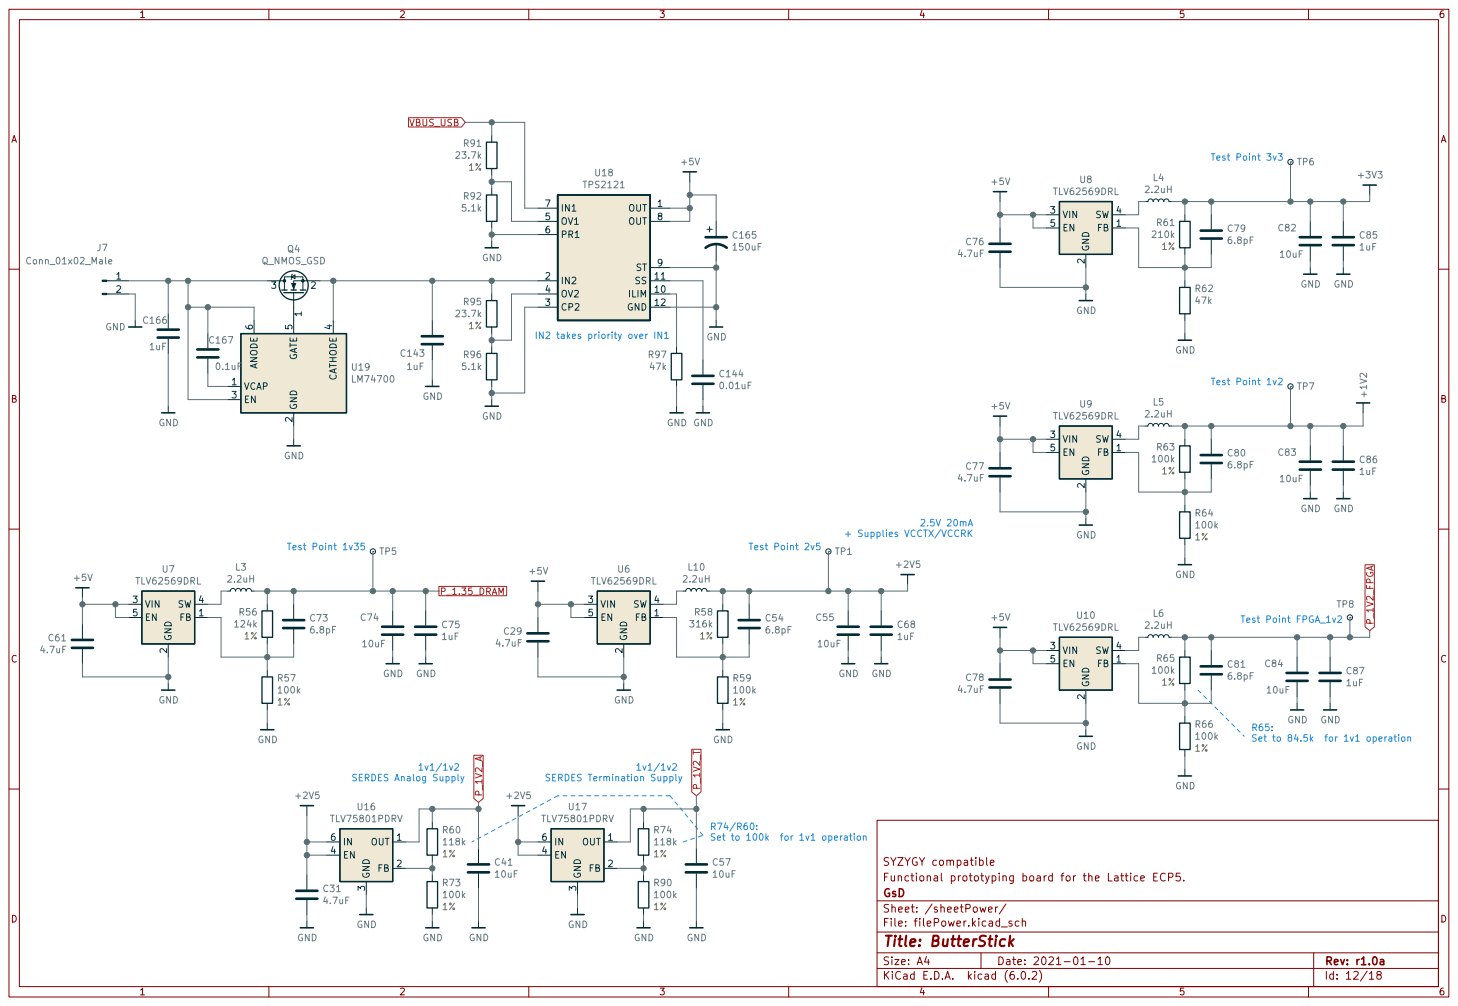
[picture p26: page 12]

2 VIN 3 SW 4 EN 5 U9 TLV62569DRL +5V GND

2 VIN 3 SW 4 EN 5 U6 TLV62569DRL TP8 GND

R74/R60: Set to 100k for 1v1 operation

Functional prototyping board for the Lattice ECP5.
File: filePower.kicad_sch Sheet: /sheetPower/ GsD


SYZYGY compatible
Functional prototyping board for the Lattice ECP5.
Sheet: /Memory-DDR3L/ GsD


SYZYGY compatible GND GND

Functional prototyping board for the Lattice ECP5.
Sheet: /Memory-DDR3L/DDR3L1/ GsD


SYZYGY compatible GND GND

Functional prototyping board for the Lattice ECP5.
Sheet: /Memory-DDR3L/DDR3L/ GsD


2 VIN 3 SW 4 EN 5 U13 TLV62569DRL TP9 GND

SYZYGY compatible
Functional prototyping board for the Lattice ECP5.
File: SyzygyStandard.kicad_sch Sheet: /SYZYGY-0-STD/ GsD


2 VIN 3 SW 4 EN 5 U14 TLV62569DRL TP10 GND

SYZYGY compatible
Functional prototyping board for the Lattice ECP5.
File: SyzygyStandard.kicad_sch Sheet: /SYZYGY-1-STD/ GsD


SYZYGY compatible
Functional prototyping board for the Lattice ECP5.
File: Syzygy-TXR4.kicad_sch Sheet: /SYZYGY-2-TXR4/ GsD

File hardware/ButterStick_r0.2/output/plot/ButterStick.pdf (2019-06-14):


PCBSpecs.sch TestPoints TestPonts.sch

File: ButterStick.sch Sheet: / GsD


File: fileIO.sch Sheet: /sheetIO/ GsD


GND GND

JD1_0001NL ETH_A_P

ETH_A_N

ETH_B_P
ETH_B_N

ETH_C_P
ETH_C_N

ETH_D_P

File: fileEthernet.sch Sheet: /sheetEthernet/ GsD


File: SmartVIO.sch Sheet: /SmartVIO/ GsD



3 SDA 4 SCL 5 ADR0 6 U17 DAC081C081CIMK GND GND



3 SDA 4 SCL 5 ADR0 6 U12 DAC081C081CIMK GND GND



3 SDA 4 SCL 5 ADR0 6 U2DAC081C081CIMK GND GND


File: filePower.sch Sheet: /sheetPower/ GsD


File: fileFPGA.sch Sheet: /sheetFPGA/ GsD



Stackup
1/2 oz 1/2 oz 1/2 oz 1/2 oz 1/2 oz + plating

Technical Specification:
4 mil 4 mil 4 mil 4 mil Finished Board Thickness: 62 mil +/- 10%
Number of Layers: 6 Base Material Generic FR4. Apply White silkscreen ledgend top & bottom pads.

Layer Order shown in table. Surface Finish: ENIG
Green Soldermask on top and bottom sides of board

Impedance control, values shown in table


File: TestPonts.sch Sheet: /TestPoints/ GsD

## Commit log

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2019-03-03 Added WIP KiCad files into source control
    [ButterStick.kicad_pcb, ButterStick.sch, fileEthernet.sch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]
2019-03-05 Update Board. - Added more signal breakouts - Tidy up some pairs - Neaten up some length matching. - Connect RGMII
    [ButterStick.kicad_pcb, fileFPGA.sch, fileHyperRAM.sch]
2019-03-06 Updated PCB. Routed all SYZYGY signals needed from the FPGA.
    [ButterStick.kicad_pcb, fileFPGA.sch, fileHyperRAM.sch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]
2019-03-07 Update schematic hieracy layout.
    [ButterStick.kicad_pcb, ButterStick.sch, SYZYGY_PORT0.sch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]
2019-03-09 Routed all SYZYGY ports. Placed decoupling caps etc.
    [ButterStick.kicad_pcb, ButterStick.sch, SYZYGY_PORT0.sch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]
2019-03-09 Switch FLASH to SO-8W footprint. Updated Routing of some componests. Re-arrange VCCIO power supplies.
    [ButterStick.kicad_pcb, SyzygyStandard.sch, fileHyperRAM.sch]
2019-03-10 Added ESD on SD card signals.
    [ButterStick.kicad_pcb, ButterStick.sch, SYZYGY_PORT0.sch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]
2019-03-10 Finished initial routing of PCB.. Most parts are finished.
    [ButterStick.kicad_pcb, ButterStick.sch, SYZYGY_PORT0.sch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]
2019-03-15 Update KiCad PCB.
    [ButterStick.kicad_pcb, ButterStick.sch, SYZYGY_PORT0.sch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]
2019-03-15 Update two diff-pairs from L6 onto L3. Update Images
    [ButterStick.kicad_pcb]
2019-03-21 Finalised part values update BOM values to reflect. Swapped layers 4/5 due to stackup changes
    [ButterStick.kicad_pcb, ButterStick.sch, SYZYGY_PORT0.sch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]
2019-06-14 Move ButterStick hw files into r0.1
    [ButterStick.csv, ButterStick.kicad_pcb, ButterStick.sch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]
2019-06-14 Add new hw version r0.2
    [ButterStick.csv, ButterStick.kicad_pcb, ButterStick.sch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]
2020-04-04 hw.r0_3: Create initial project
    [ButterStick.kicad_pcb, ButterStick.sch, FPGA-DDR3L.sch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]
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2020-04-04 hw.r0_3: Experiment with buses
    [ButterStick.kicad_pcb, ButterStick.sch, DDR3L.sch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]
2020-04-05 hw.r0_3: cleanup and additions
    [ButterStick.kicad_pcb, ButterStick.sch, DDR3L.sch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]
2020-04-06 hw.r0_3: Update schematics with 85F-5G symbol
    [ButterStick.kicad_pcb, ButterStick.sch, DDR3L.sch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]
2020-04-23 hw.r0_3: Start pin assignments for DDR3
    [ButterStick.kicad_pcb, ButterStick.sch, DDR3L.sch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]
2020-05-26 hw.r0_3: Update schematics to new KiCad format
    [ButterStick.kicad_pcb, ButterStick.kicad_sch, DDR3L.kicad_sch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]
2020-05-26 hw.r0_3: Remove old format schematics
    [ButterStick.sch, DDR3L.sch, FPGA-5G.sch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]
2020-05-26 hw.r0_3: routing improvements
    [ButterStick.kicad_pcb, ButterStick.kicad_sch, DDR3L.kicad_sch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]
2020-05-28 hw.r0_3: Start routing DDR3 interface
    [ButterStick.kicad_pcb, ButterStick.kicad_sch, DDR3L.kicad_sch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]
2020-05-29 hw.r0_3: Inital routing of DDR3 done
    [ButterStick.kicad_pcb, ButterStick.kicad_sch, DDR3L.kicad_sch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]
2020-05-29 hw.r0_3: routed SYZYGY, begin routing RGMII/ULPI
    [ButterStick.kicad_pcb, ButterStick.kicad_sch, DDR3L.kicad_sch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]
2020-05-30 hw.r0_3: major blocks roughly routed
    [ButterStick.kicad_pcb, ButterStick.kicad_sch, DDR3L.kicad_sch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]
2020-06-21 hw.r0d3: Length matched all SYZYGY ports
    [ButterStick.kicad_sch, DDR3L.kicad_sch, FPGA-5G.kicad_sch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]
2020-06-22 hw.r0d3: update routing
    [ButterStick.kicad_sch, DDR3L.kicad_sch, FPGA-5G.kicad_sch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]
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2020-06-23 hw.r0d3: update DDR3 pinmap and routing
    [ButterStick.kicad_sch, DDR3L.kicad_sch, FPGA-5G.kicad_sch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]
2020-07-12 hw.r0d3: complete first pass of routing
    [ButterStick.kicad_sch, DDR3L.kicad_sch, FPGA-5G.kicad_sch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]
2020-07-12 hw.r0d3: Updated all DCDC supplies Added serdes power supplies
    [ButterStick.kicad_sch, DDR3L.kicad_sch, FPGA-5G.kicad_sch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]
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2020-07-14 hw.r0d3: Small routing tweaks
    [ButterStick.kicad_sch, DDR3L.kicad_sch, FPGA-5G.kicad_sch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]
2020-07-14 hw.r0d3: tweak length matching
    [ButterStick.kicad_sch, FPGA-5G.kicad_sch, FPGA-MISC.kicad_sch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]
2020-07-14 hw.r0d3: Fix ULPI VCCIO
    [ButterStick.kicad_sch, FPGA-DDR3L.kicad_sch, FPGA-MISC.kicad_sch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]
2020-07-14 hwr0d3: fix tie ULPI clkout HIGH
    [ButterStick.kicad_sch, SyzygyStandard.kicad_sch, fileIO.kicad_sch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]
2020-07-14 hw.r0d3: fix ULPI power supplies, ID pin
    [ButterStick.kicad_sch, usb-phy.kicad_sch]
2020-07-15 hw.r0d3: Remove inverted SYZYGY pairs.
    [ButterStick.kicad_sch, DDR3L.kicad_sch, FPGA-5G.kicad_sch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]
2020-07-15 hw.r0d3: Update led symbol to match footprint.
    [FPGA-DDR3L.kicad_sch, FPGA-MISC.kicad_sch, FPGA-SYZGY0.kicad_sch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]
2020-07-16 hw.r0d3: Update schematic bus routing
    [ButterStick.kicad_sch, DDR3L.kicad_sch, FPGA-5G.kicad_sch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]
2020-07-16 hw.r0d3: Update r03 name to r1.0. Add fiducials
    [ButterStick.kicad_sch, DDR3L.kicad_sch, FPGA-5G.kicad_sch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]
2020-07-16 hw.r0d3: Update power path
    [ButterStick.kicad_sch, DDR3L.kicad_sch, filePower.kicad_sch]
2020-07-16 hw.r1d0: Move PCB source to r1d0 folder.
    [ButterStick.kicad_sch, DDR3L.kicad_sch, FPGA-5G.kicad_sch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]
2020-07-17 hw.r1d0: Review complete, gerbers generated
    [ButterStick.kicad_sch, DDR3L.kicad_sch, FPGA-5G.kicad_sch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]
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2020-07-18 hw.r1d0: Update BOM fieids in schematic.
    [ButterStick.kicad_sch, DDR3L.kicad_sch, FPGA-5G.kicad_sch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]
2020-11-01 hw.r1d0: Fix RGMII straps
    This commit correctly sets the stop resistos on the RGMII lines to 1K5
    instead of DNP.
    Also regenerate and add a schematic in PDF format.
    Fixes #6
    [ButterStick.kicad_sch, DDR3L.kicad_sch, FPGA-5G.kicad_sch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]
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2021-01-10 hardware.r1d0: Update BOM values in schematic
    Regenerate schematics and export BOM
    Fixes #9
    [ButterStick-r1.0-bom.csv, ButterStick.kicad_sch, DDR3L.kicad_sch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]
2021-01-10 hardware.r1d0: Tidy up BOM entries
    Export HTML Interactive BOM
    [ButterStick-r1.0-bom.csv, ButterStick.kicad_sch, Syzygy-TXR4.kicad_sch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]
2021-01-10 hardware.r1d0: Update USB0.reset pull
    - Swap pulldown for pullup and re-route
    - Regenerate gerbers, and schematic
    - Update revision to r1.0a to reflect a hardware change
    - Update silkscreen date
    Fixes #8
    [ButterStick-r1.0-bom.csv, ButterStick-r1.0a-bom.csv, ButterStick.kicad_sch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]
2021-03-25 hw.r1d0: Add position files
    [ButterStick-r1.0a-bottom-pos.csv, ButterStick-r1.0a-top-pos.csv]
2021-11-28 mechanical/case: add acrylic plate design
    [butterstick_acrylic_plate.dxf, butterstick_acrylic_plate.scad]
2021-12-04 contrib: Add OpenOCD config
    [butterstick.cfg]
2021-12-04 contrib: Update openocd config
    [butterstick.cfg]
2022-06-07 Fix RGB G/B signals
    - Corrects a mistake where blue and green signals were swapped
    - Regenerate schematic
    Closes #12
    [ButterStick.kicad_sch, DDR3L.kicad_sch, FPGA-5G.kicad_sch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]
